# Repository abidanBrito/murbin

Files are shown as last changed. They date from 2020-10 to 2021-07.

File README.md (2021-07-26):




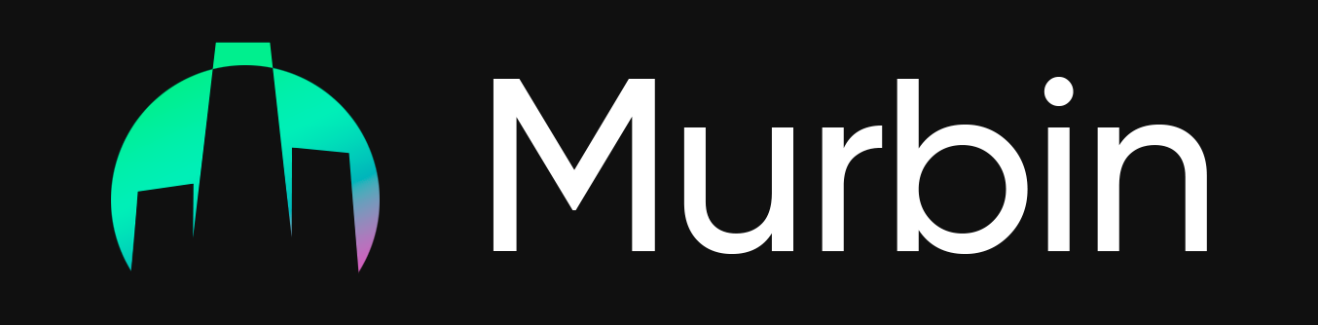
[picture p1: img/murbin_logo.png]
Project_Logo


## TABLE OF CONTENTS
1.  [Motivation](#motivation)
2.  [Technologies and Frameworks](#technologies-and-frameworks)
3.  [System Architecture](#system-architecture-outdated-diagram)
4.  [Functionalities and Features](#functionalities-and-features)
5.  [Documentation](#documentation)
6.  [Acknowledgements](#acknowledgements)

## MOTIVATION
This project is a team effort for our third semester class **Internet of Things** (IoT). It aims to implement **smart streetlighting** in a way that is **not only efficient**, but also provides some **added functionalities** and interaction with the user via an **Android App**.

## TECHNOLOGIES AND FRAMEWORKS
### Electronic Devices and Components
*   **Raspberry Pi 3 B**.
*   **ESP32 Devkit v1 WiFi + Bluetooth**.
*   **M5Stack** Modular Rapid Prototyping.
*   MQ-135 **Gas Sensor** Module.
*   DHT11 **Temperature and Humidity Sensor** Module.
*   KY-038 **Microphone Sound Sensor** Module.
*   HC-SR501 **PIR Sensor** Module. 
*   **Sonoff Touch** with Tasmota Firmware.
*   Operational Amplifiers.
*   Yxo Yuxinou **LED COB Chip** (220-265V/AC, 20W, 3500k/450nm/380-780nm).
*   NeoPixel Ring - **24 x 5050 RGB LED** with Integrated Drivers
*   Photodiode.
*   Resistors.
*   Relay.

### Mobile / Cloud Platforms & Protocols
*   **Android Things** embedded Operating System.
*   **Firebase**. 
*   **MQTT**.
*   **UDP**.

### Software Development 
*   Arduino IDE. 
*   Android Studio.
*   FreeRTOS.   

## SYSTEM ARCHITECTURE (OUTDATED DIAGRAM)
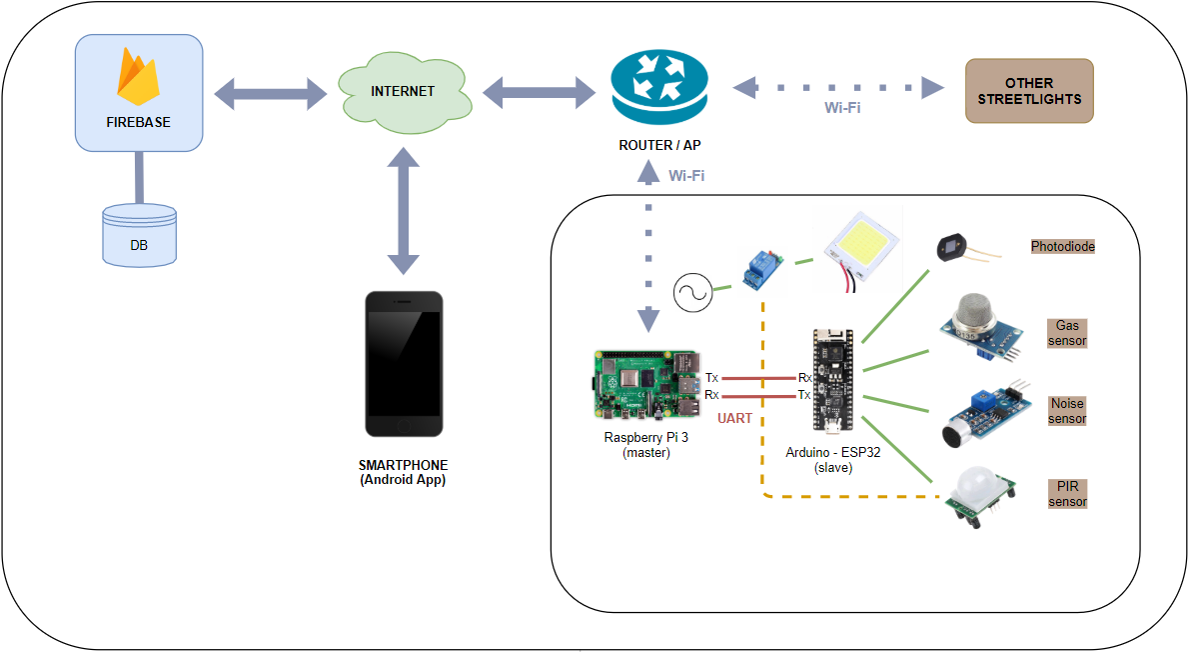
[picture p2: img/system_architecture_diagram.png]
System Architecture Diagram

Refer to the [documentation](docs/Documento_Técnico_Diseño_v3.pdf) (spanish) for further details and schematics.

## FUNCTIONALITIES AND FEATURES 
*   \[x] High **CO2 and Pollution** Detection.
*   \[x] **Temperature and Humidity** Sensor.
*   \[x] **Noise** Sensor.
*   \[x] **Motion Detection**.
*   \[x] **Luminosity** Sensor.
*   \[x] **Flashing LED** alarms.
*   \[x] Interactive **Mobile App** (ON/OFF switch, sensor readings, geolocation, map subzones and different user roles).
*   \[x] **Light Sleep** Mode.
*   \[x] **PCB** design.
*   \[ ] Dimming LED.

## DOCUMENTATION
It can be found in the form of a PDF file for each and every Sprint, accordingly. Those of previous Sprints may contain errors (schematics, pins, etc.). Please, refer to the lastest version: [technical documentation](docs/Documento_Técnico_Diseño_v3.pdf) (spanish). 

## ACKNOWLEDGEMENTS
We would like to express our sincere gratitude to our **professors** for their invaluable support, feedback and encouragement throughout the development of this project, and to **Universitat Politècnica de València** for providing us with both the knowledge and the tools needed to complete it.

## LICENSE
This repository is released under the MIT license. See [LICENSE.md](LICENSE.md) for more information.

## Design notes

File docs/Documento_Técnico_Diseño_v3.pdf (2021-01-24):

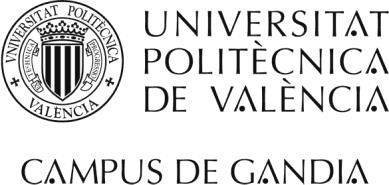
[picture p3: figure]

## Proyecto GTI_2A (GTI_2A_20_TEAM_12)

## Murbin - Farolas inteligentes

## Documento Técnico de Diseño

### Volumen 2

Documento Técnico de Diseño | Pag.ii
GTI_2A_20_TEAM_12
Vol. 1

### ÍNDICE

1.3 EQUIPO DE DESARROLLO E INTERESADOS EN EL PROYECTO ........4

Documento Técnico de Diseño | Pag.1

### 1 INTRODUCCIÓN

Murbin (Mobiliario urbano inteligente) plantea un prototipo de alumbrado público inteligente. Más concretamente, en nuestro caso, ser un sistema inteligente implica varias cosas: la conexión a Internet, la capacidad de realizar lecturas de diversas magnitudes físicas, así como la transmisión de éstas a posteriori y la activación automática de comportamientos preestablecidos (actuadores) en función del valor de medidas nominales. Por tanto, se trata de un proyecto que recae sobre el marco del Internet de las cosas (IoT) y requiere de numerosas tecnologías y disciplinas de la ingeniería.

Se recopila información sensible de campo, a fin de monitorizar y optimizar la actividad ambiental (intensidad de la luz, contaminación, nivel de ruido, presencia humana, geolocalización del dispositivo, etc.). Se propone implementar también un mecanismo de autoabastecimiento (célula fotovoltaica, batería y convertidor buck-boost). Para minimizar el consumo energético, se prevee la realización de las mediciones cada cierto tiempo. Ésto es configurable. Inmediatamente entraría en modo de hibernación o stand-by, hasta la siguiente captura de datos o el acaecimiento de una interrupción producida por alguna subrutina.

Para implementar las susodichas funcionalidades, se ha optado por utilizar el microcontrolador ESP32 (como esclavo), y el micro-ordenador Raspberry Pi 3 (como maestro). También son necesarios múltiples dispositivos y componentes electrónicos (resistencias, amplificadores operacionales, diodos, termistores, sensores específicos, …). El ESP32 puede ser programado utilizando la plataforma de desarrollo Arduino.

### 1.1 PROPÓSITO

En este documento se especifica el planteamiento inicial de las características técnicas del producto, así como su funcionamiento. Además, proporciona información sobre los dispositivos y tecnologías utilizados. Éste es un documento técnico dirigido a un público con conocimiento tecnológico mínimo, relativo al campo de la electrónica y la programación. Su redacción pretende exponer de manera rigurosa y objetiva las capacidades, propiedades y limitaciones del sistema. Con ello, se espera concretar las amplias posibilidades del producto.

### 1.2 ALCANCE

El término de alumbrado público inteligente hace referencia a alumbrado capaz de detectar diferentes niveles de magnitud y adaptar la intensidad de la luz de manera proporcional. Es decir, para diferentes condiciones la actuación de la farola será diferente. La intensidad baja cuando no se detecta movimiento y, por el contrario, sube cuando se detecta. Esto supone un cambio drástico de paradigma; contrasta con el tradicional alumbrado estático de intensidad variable por tiempos fijos (programado con reloj). Las posibilidades se extienden más allá de la luminosidad, permitiéndonos interactuar con los usuarios del medio público de manera acorde a la situación. Otro ejemplo sería el de cambiar la temperatura de los haces de luz en función del nivel de ruido del entorno. Así pues, es un sistema directamente ligado al desarrollo y la evolución de las Smart Cities [1] [2] [3].

Aclarado esto, los objetivos del producto son la optimización y reducción del consumo energético, el control de la contaminación en sus múltiples expresiones (sonora, lumínica y CO2), mejorar la experiencia de usuario del viandante y la creación de una interfaz homogénea y céntrica (aplicación Android) para consultas varias: búsqueda de parking, trazado de caminos, alertas personalizadas en función del nivel de ruido u otras magnitudes de interés, mapas de calor y un largo etcétera.

También estará equipado con un sistema de posicionamiento global, bien sea un recibidor GPS físico (hardware) o un par de coordenadas geográficas fijadas durante la instalación (software). Además el dispositivo ha de ser hermético; se puede estropear si alguno de sus componentes internos entra en contacto con el agua, provocando un cortocircuito.

Cabe recalcar que solo se han mencionado algunas de las funcionalidades pensadas desde un punto de vista empático con el perfil de usuario del viandante. No obstante, se han definido otros perfiles como el del técnico, el administrador y (opcionalmente) el investigador o científico. Las funcionalidades a implementar deberán ser específicas (por lo general) al tipo de usuario en cuestión. Véanse debajo los perfiles de usuario estudiados y los porcentajes aproximados que se sopesan.

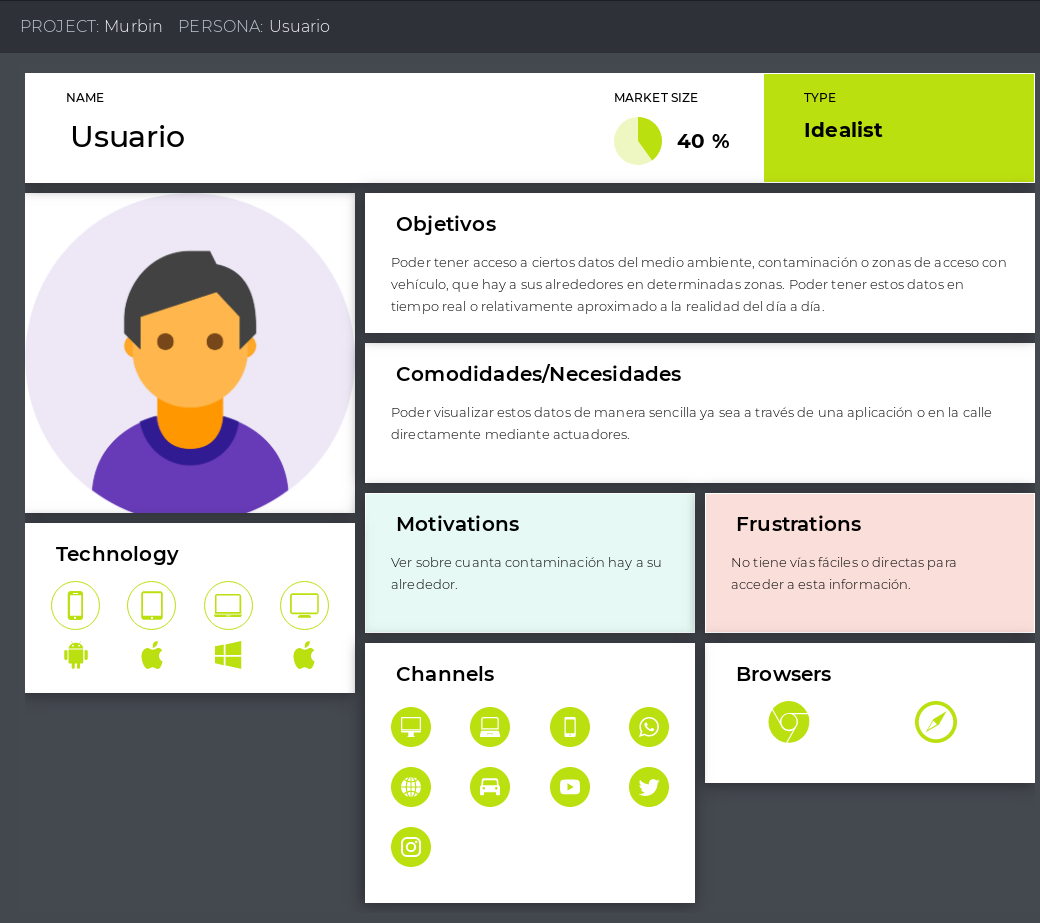
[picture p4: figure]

Ilustración 1. Perfil de usuario (usuario).

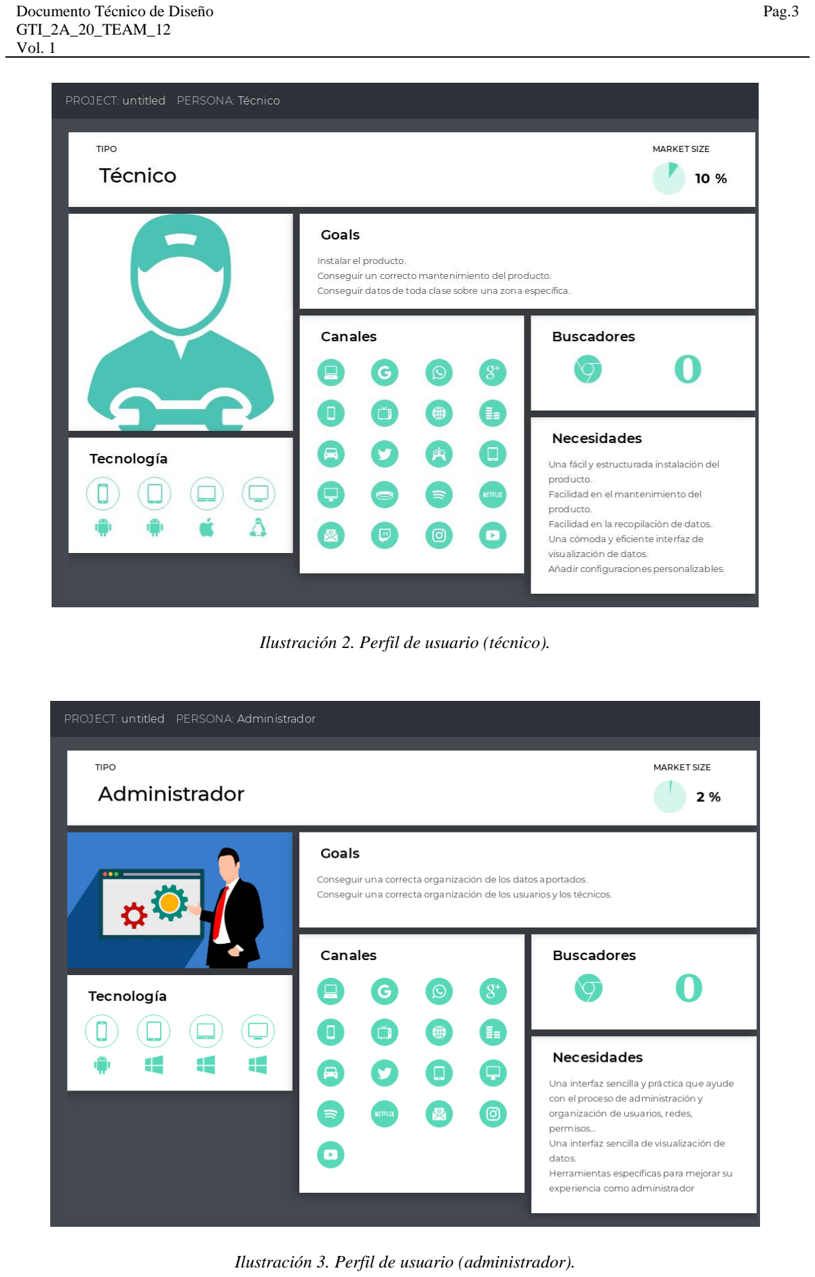
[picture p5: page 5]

Ilustración 2. Perfil de usuario (técnico).

Ilustración 3. Perfil de usuario (administrador).

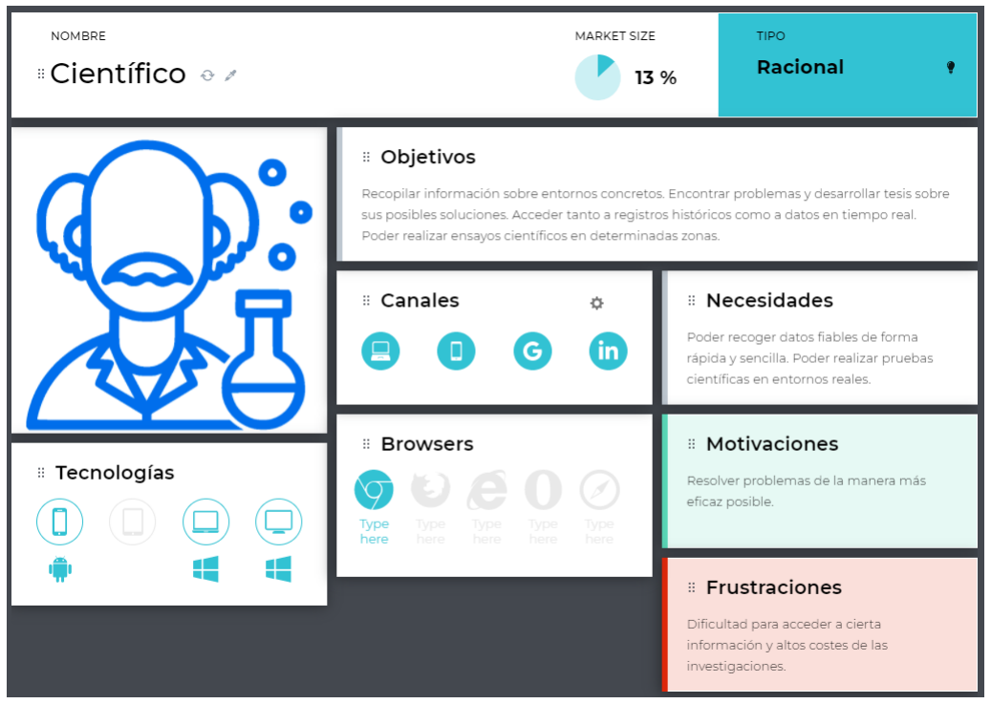
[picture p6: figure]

Ilustración 4. Perfil de usuario (científico).

### 1.3 EQUIPO DE DESARROLLO E INTERESADOS EN EL PROYECTO

A continuación se listan todos los integrantes del equipo de desarrollo del proyecto, así como algunas personalidades de interés por su carácter asesorativo y/o de formación.

Miembros del equipo

Abidán Brito Clavijo

- Estudiante de 2º del grado en Tecnologías Interactivas.
- Manager del equipo.
- Desarrollo electrónico.
- Desarrollo software embebido.

Alejandro Losa García

- Estudiante de 2º del grado en Tecnologías Interactivas.
- Diseño visual y de interacción.
- Maquetación interfaz gráfica.

Francisco Javier Paños Madrona

- Estudiante de 2º del grado en Tecnologías Interactivas.
- Desarrollo de aplicación Android.

Yeray Candel Sampedro

- Estudiante de 2º del grado en Tecnologías Interactivas.
- Desarrollo electrónico.
- Desarrollo software embebido.

Raúl De La Fe Robles

- Estudiante de 2º del grado en Tecnologías Interactivas.
- Generalista.

Otros interesados en el proyecto

José Marín-Roig Ramón

- Profesor Titular en Universitat Politècnica de València.
- Product Owner.
- Asesor.

Jesús Tomás Gironés

- Profesor Titular en Universitat Politècnica de València.
- Formación teórica Android.
- Asesor.

Stella María Heras Barberá

- Profesora Asociada en Universitat Politècnica de València.
- Formación práctica Android.
- Asesora.

Enrique Colomar Pous

- Profesor Titular en Universitat Politècnica de València.
- Formación práctica de laboratorio (desarrollo electrónico).

Tomás Carlos Sogorb Devesa

- Profesor Titular en Universitat Politècnica de València.
- Formación teórica microprocesadores y acondicionadores de señal.

### 1.4 DEFINICIONES, ACRÓNIMOS Y ABREVIATURAS

- IDE: entorno de desarrollo integrado (Integrated Development Environment).
- TCP: Transmission Control Protocol.
- IP: Internet Protocol address.
- UDP: User Datagram Protocol.
- HTTP: Hypertext Transfer Protocol.
- MQTT: Message Queuing Telemetry Transport.
- UART: Universal Asynchronous Receiver-Transmitter.
- GPS: Global Positioning System.

### 1.5 ESTRUCTURA DEL DOCUMENTO

El documento se estructura de la siguiente manera:

/1 | La Sección 1 es la introducción e incluye una descripción detallada del proyecto y los documentos referenciados.
/2 | La Sección 2 proporciona una visión general del sistema.
/3 | La Sección 3 incluye el mapa de la red de nodos especificando las diferentes capas
/4 | La Sección 4 presenta las conclusiones del trabajo desarrollado y las posibles líneas de mejora.
/5 | Por último, se presentan las referencias del documento

### 1.6 REPOSITORIO GIT Y LISTADO DOCUMENTAL

Para la base de código y documentos pertinentes a este proyecto, se ha utilizado un repositorio Git como sistema de control de versiones, alojado en la plataforma GitHub. Para acceder al repositorio, haga click sobre el hipervínculo aquí expuesto:

https://github.com/abidanBrito/murbin

### 2 SISTEMA

### 2.1 CARACTERÍSTICAS DEL SISTEMA

El sistema aquí expuesto parte del microcontrolador ESP32 V1, o un M5Stack acoplado al micro-ordenador Raspberry Pi 3. De esta manera podemos tener una red de sensores centralizada. Además, no es necesario el uso de un convertidor Analógico-Digital externo.

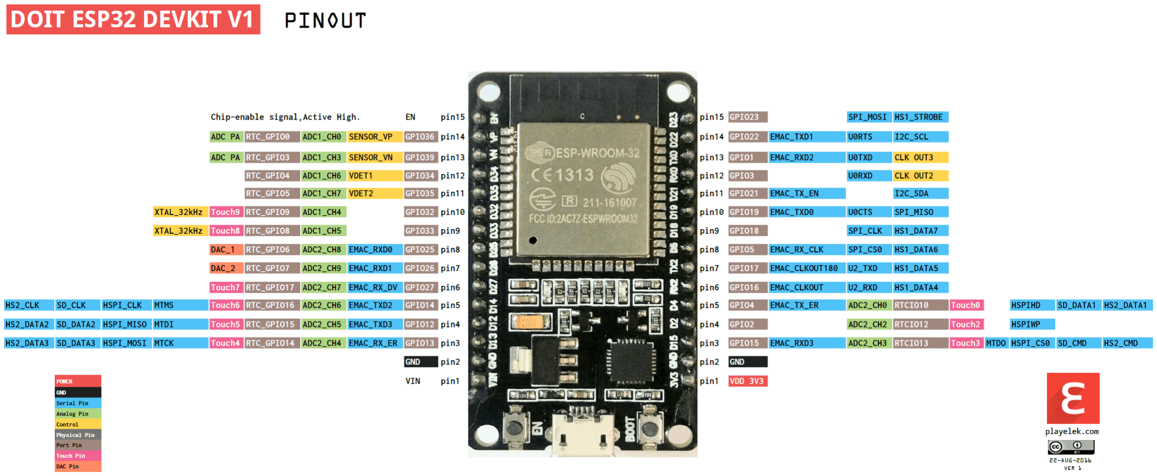
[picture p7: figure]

Ilustración 5. Esquema de pines del ESP32.

Lo primero que se debe hacer es establecer una línea de tierra. Los pines de GND han de coincidir, y se ha de tener especial precaución con el sentido en que se acoplan los pines. Si se hiciese en una orientación errónea, se podría cortocircuitar la placa.

El circuito del Transmisor-Receptor Asíncrono Universal (UART) controla los puertos y dispositivos serie. Se utilizará para interconectar el microprocesador y el microcontrolador, mediante un protocolo de comunicación en serie. De esta manera permitimos el análisis en tiempo real con el monitor en serie del Arduino IDE o el equivalente Logcat del Android Studio. La velocidad de transferencia ha de ser la misma para maestro y esclavo, para que la transmisión de datos coincida. Nótese que la placa ESP32 solo tiene un UART. Es decir, no pueden haber varios periféricos conectados al mismo tiempo por la misma UART. La transmisión/recepción de datos se lleva a cabo por los pines TXD y RXD. No obstante, al conectar la placa al PC por el puerto microUSB, se conecta directamente al UART.

Nuestro sistema realiza lecturas analógicas de los diversos sensores a través de los pines GPIO. La mayoría de estos pines se enc uentran conectados internamente a un ADC (convertidor analógico-digital).

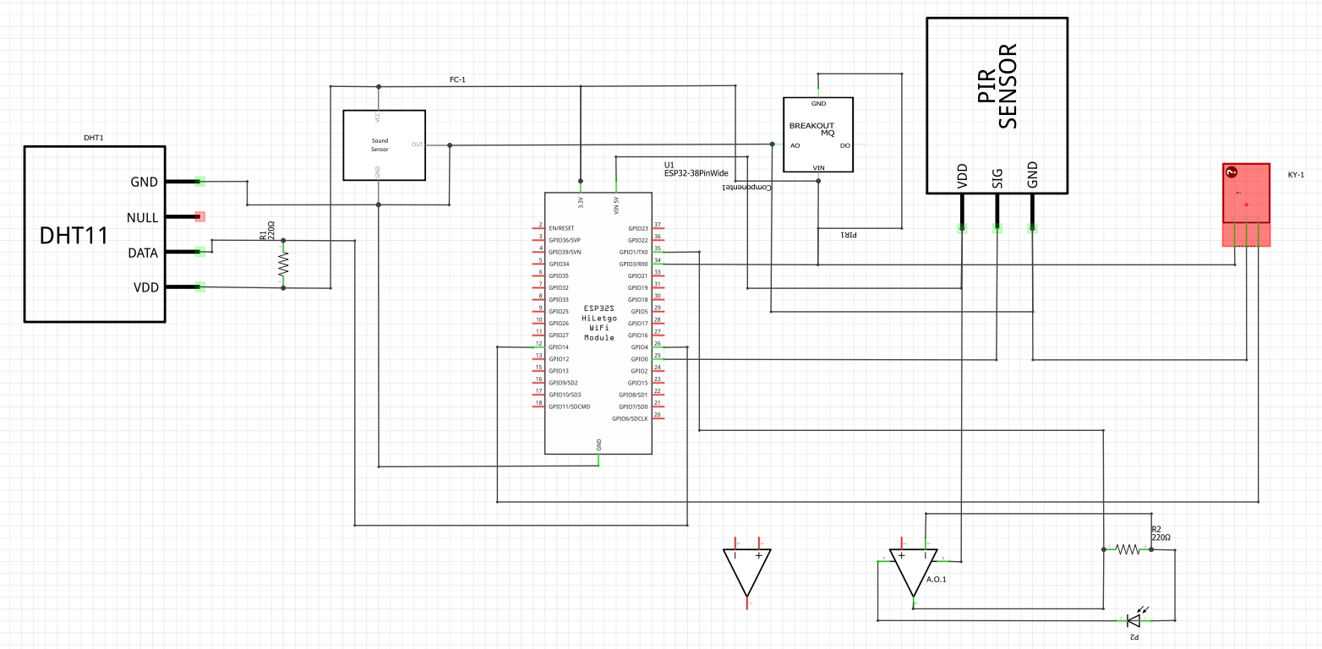
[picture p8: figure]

Ilustración 6. Esquemático de los sensores.

La directiva 2011/65/UE es aplicable. El producto también cumple la normativa europea de concentración máxima de sustancias peligrosas. El reciclaje de aparatos eléctricos y electrónicos es una cuestión sensible. Éstos están formados por diferentes materias peligrosas. La negligencia de su correcto tratamiento o reciclaje puede suponer contaminación ambiental. Siguiendo el Real Decreto 110/2015, se insta a extraer los componentes internos de la caja y llevarlos al punto limpio más cercano; depositando la caja y los residuos electrónicos por separado y en sus respectivas localizaciones. El reciclaje de los RAEE depende del papel activo de Documento Técnico de Diseño Pág.9 GTI 1A 19 TEAM 02 Vol. 1 cada uno de nosotros. Debemos concienciarnos y entender la responsabilidad y deuda ecológica que ello conlleva. Todos los sensores implementados cumplen la normativa RoHS: MPU-9250, BMP280, A2235-H.

### 2.2 ARQUITECTURA DEL SISTEMA

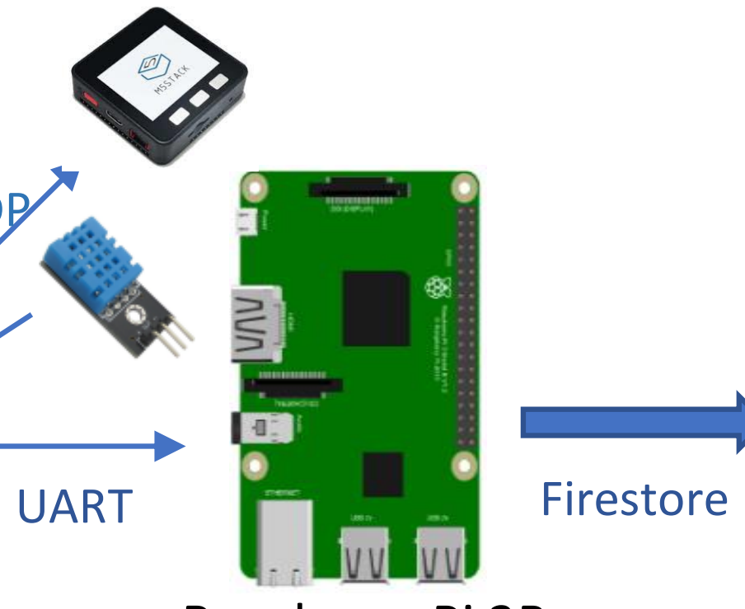
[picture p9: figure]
UART; Firestore
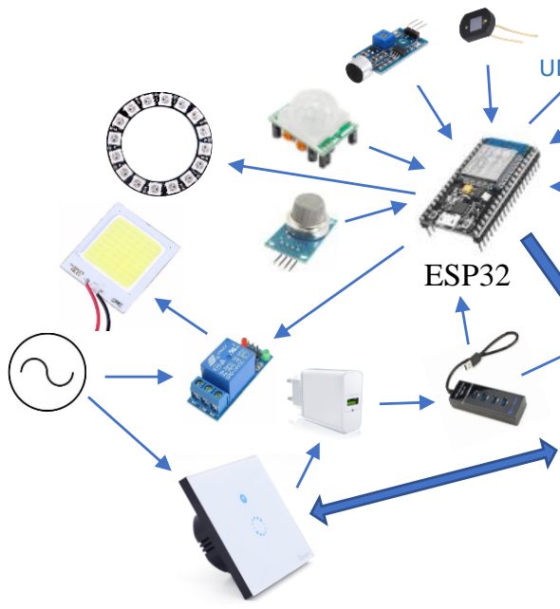
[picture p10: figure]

Ilustración 7. Diagrama de conexiones del sistema.

ESP32 | Raspberry Pi 3B

Smartphone

Broker
MQTT

Sonoff Touch
conexión inalámbrica
conexión por cable

UDP

Ilustración 8. Diagrama de Comunicaciones del sistema.

MQTT
murbin/
ON / OFF

murbin/
TOGGLE

MQTT

murbin/sensores/tipo_sensor MEDICION

Firestore

streetlight/sensors/tipo_sensor value=numero

MQTT

murbin/
ON / OFF

Firestore
streetlight/sensors/tipo_sensor value=numero

zones/subzones/streetlights
Firestore | name=string
users/
value=id

UART
(testeo)

UDP

### 3 RED DE NODOS

Se puede desglosar el camino de los datos de manera esquemática en los siguientes 5 niveles:
1. Comunicación hardware (nivel 0).
2. Acceso a la red (nivel 1).
3. Internet (nivel 2).
4. Transporte (nivel 3).
5. Aplicación (nivel 4).

En primer lugar nuestro microcontrolador realiza lecturas analógicas de los sensores a través de los pines GPIO, y con la Raspberry Pi mediante el protocolo UART (con la finalidad de enviar los datos capturados). Éstos, son enviados mediante conexión inalámbrica (Wi-Fi) a un servidor en la nube y almacenados en una base de datos NoSQL (Firebase), utilizando el protocolo IP. Ya que la conexión a Internet es la función que más consume, y no es necesario enviar datos en grandes cantidades, se podría utilizar el protocolo TCP o el UDP. Finalmente estos datos acaban en el servidor web mediante el protocolo HTTP. Nótese que, en la práctica no sería necesario tener el prototipo conectado a ningún otro dispositivo, pues es autosuficiente y los datos serían enviados directamente al servidor. A continuación, adjuntamos la siguiente ilustración a modo de ayuda visual. También se utiliza el protocolo MQTT como pasarela de comunicación entre los distintos dispositivos, para el envío y recepción de datos.

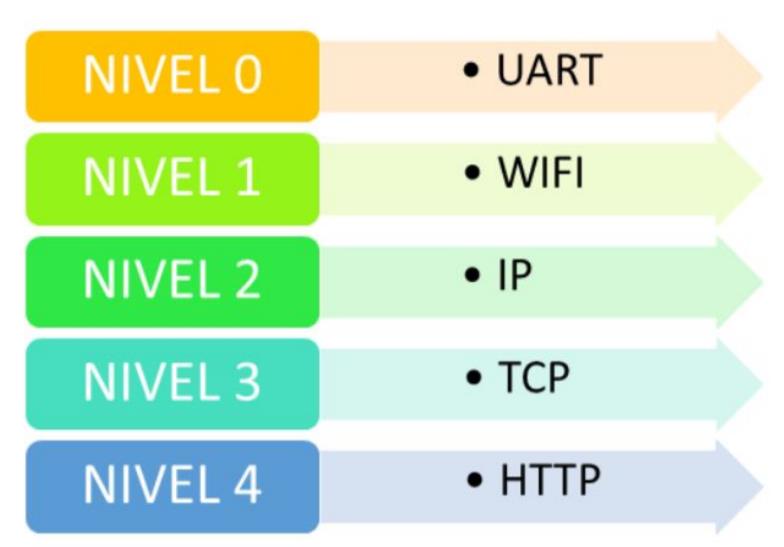
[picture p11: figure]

Ilustración 9. Red de nodos.

### 4 FUNCIONALIDADES SENSOR

### 4.1 SENSOR KY-038

El sensor de sonidoKY038 para Arduino está diseñado con un pequeño micrófono electrito que detecta las variaciones de ruido del ambiente.

Los micrófonos electret tienen una respuesta en frecuencia bastante buena (50 a 15.000 Hz) y una sensibilidad entre -50 dB y -70 dB, aunque lejana de la de los micrófonos de condensador, que son mucho más sensibles en la zona de los agudos). Además, es una respuesta poco plana.

Entre sus principales ventajas destaca su insensibilidad a la humedad y el calor (aunque la humedad y las partículas causen un cortocircuito en parte del diafragma, siempre se obtiene señal eléctrica a la salida).

El principal inconveniente que presentan los micrófonos electret es el polvo, que deteriora su rendimiento con el uso. Cuando un micrófono electret empieza a producir zumbidos (ruidos) inexplicables, es una indicación de que debe ser sustituido, ya que ha terminado su vida activa.

Puedes utilizar este sensor para tus proyectos que requieran la detección de ruido, como ser alarmas o interruptores con detección de voz o sonido (un aplauso, por ejemplo).

De manera general, estos son algunos rangos de operación típicos que son útiles de tenerlos en cuenta a la hora de implementar un circuito con este sensor.

- Voltaje de trabajo: 5.0V
- Muy bajo consumo de corriente
- Temperatura de trabajo: -40 < T < +85 ºC

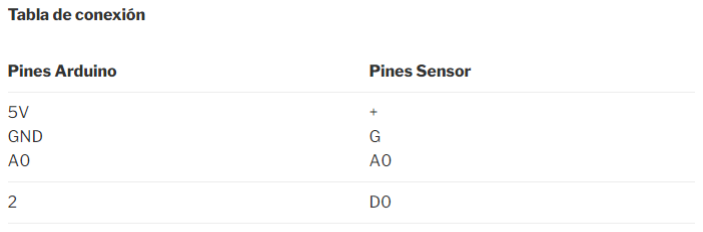
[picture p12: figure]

### 4.1.1.1 Circuito del sensor de sonido KY038

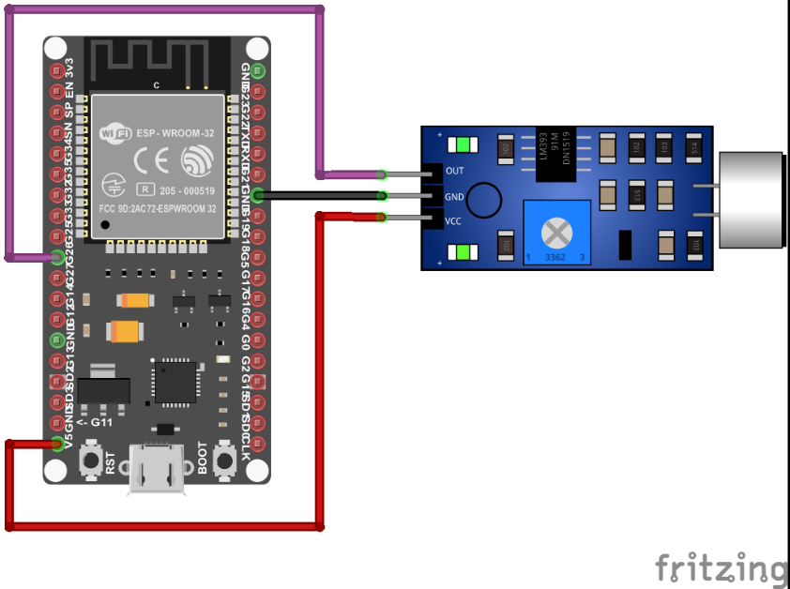
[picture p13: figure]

### 4.2 SENSOR PIR

Los detectores PIR (Passive Infrared) o Pasivo Infrarrojo, reaccionan sólo ante determinadas fuentes de energía tales como el calor del cuerpo humano o animales. Básicamente reciben la variación de las radiaciones infrarrojas del medio ambiente que cubre. Es llamado pasivo debido a que no emite radiaciones, sino que las recibe. Estos captan la presencia detectando la diferencia entre el calor emitido por el cuerpo humano y el espacio alrededor.

Su componente principal son los sensores piroeléctricos. Se trata de un componente electrónico diseñado para detectar cambios en la radiación infrarroja recibida. Generalmente dentro de su encapsulado incorporan un transistor de efecto de campo que amplifica la señal eléctrica que genera cuando se produce dicha variación de radiación recibida.

La información infrarroja llega al sensor piroeléctrico a través de una lente de fressnell que divide el área protegida en sectores. Se distribuyen lentes con diferentes características: gran angular, cortina, corredor, anti mascotas, etc.

Los sensores PIR son ampliamente usados en sistemas de seguridad y en detección de intrusos en entornos domésticos y comerciales, ya que se pueden instalar en cualquier punto de entrada potencial (puertas y ventanas) y avisar de la presencia de los intrusos antes de que lleguen al sensor y lo puedan sabotear.

### 4.2.1.1 Circuito del sensor PIR

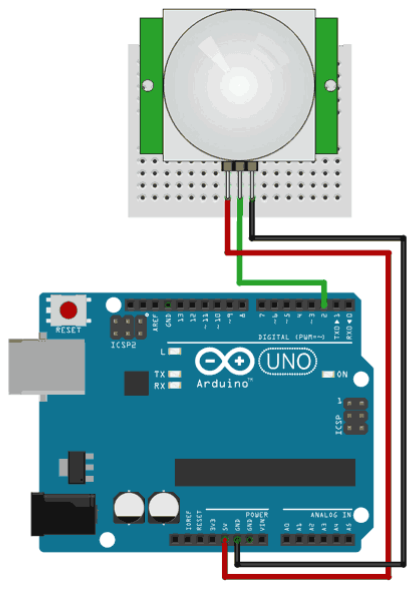
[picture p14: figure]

### 4.3 SENSOR MQ4

Los sensores de gases MQ son una familia de dispositivos diseñados para detectar la presencia de distintos componentes químicos en el aire. Podemos conectar estos dispositivos a un autómata o procesador como Arduino.

Existe una gran variedad de sensores MQ. Cada modelo está diseñado para detectar una o más sustancias, pensadas para un uso específico, como por ejemplo detección gases inflamables, calidad del aire o detección de alcohol en aire respirado.

Los sensores de gases deben ser calibrados antes de obtener una medida precisa. Aun calibrados estos sensores no disponen de la garantía necesaria para formar parte de un sistema de seguridad.

Los sensores MQ están compuestos por un sensor electroquímico que varía su resistencia al estar en contacto con las sustancias.

Los sensores de gases son dispositivos con alta inercia, es decir, la respuesta necesita tiempos largos para estabilizarse tras un cambio de concentración de los gases medidos. Ello es debido a la necesidad física de que el gas abandone el material sensible, lo cual es un proceso lento.

Todos los modelos MQ disponen de un calentador necesario para elevar la temperatura del sensor, y que sus materiales adquieran la sensibilidad. Mientras el calentador no alcance la temperatura de funcionamiento, la lectura del sensor no será fiable.

El tiempo de calentamiento depende de cada modelo de sensor. En la mayoría de las modelos es suficiente para con unos pocos minutos, pero algunos modelos requieren hasta 12 y 48 horas hasta obtener mediciones estables.

Por otro lado, cada modelo necesita su propia tensión para alimentar el calentador. En muchos modelos esta tensión es de 5V, pero algunos modelos tienen condicionantes especiales para la alimentación.

El consumo de los sensores MQ puede ser elevado debido al calor necesario para funcionar el calentador, que puede llegar hasta 800 mW en algunos modelos. Esto es superior a la potencia que puede suministrar el regulador de Arduino, por lo que será necesario proporcionar una fuente de alimentación externa.

A continuación, una tabla de resumen con los distintos modelos de sensores disponibles, los gases a los que son sensibles, y algunos datos sobre el calentador. Nosotros utilizaremos el MQ-135.

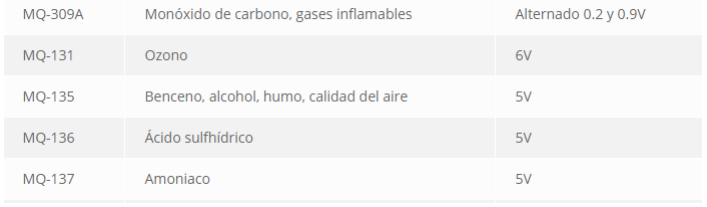
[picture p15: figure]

### 4.3.1.1 Circuito del sensor de gas MQ-4

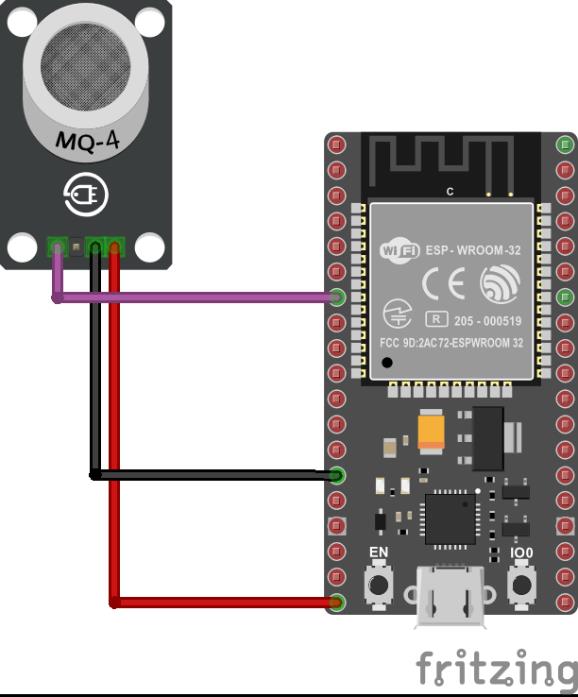
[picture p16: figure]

### 4.4 SENSOR LUMINOSIDAD

Un fotorresistor, o LDR (light-dependent resistor) es un dispositivo cuya resistencia varía en función de la luz recibida. Podemos usar esta variación para medir, a través de las entradas analógicas, una estimación del nivel de la luz.

Un fotorresistor está formado por un semiconductor, típicamente sulfuro de cadmio CdS. Al incidir la luz sobre él algunos de los fotones son absorbidos, provocando que electrones pasen a la banda de conducción y, por tanto, disminuyendo la resistencia del componente.

Por tanto, un fotorresistor disminuye su resistencia a medida que aumenta la luz sobre él. Los valores típicos son de 1 Mohm en total oscuridad, a 50-100 Ohm bajo luz brillante.

Por otro lado, la variación de la resistencia es relativamente lenta, de 20 a 100 ms en función del modelo. Esta lentitud hace que no sea posible registrar variaciones rápidas, como las producidas en fuentes de luz artificiales alimentadas por corriente alterna. Este comportamiento puede ser beneficioso, ya que dota al sensor de una gran estabilidad.

Finalmente, los fotorresistores no resultan adecuados para proporcionar una medición de la iluminancia, es decir, para servir como luxómetro. Esto es debido a su baja precisión, su fuerte dependencia con la temperatura y, especialmente, a que su distribución espectral no resulta adecuada para la medición de iluminancia.

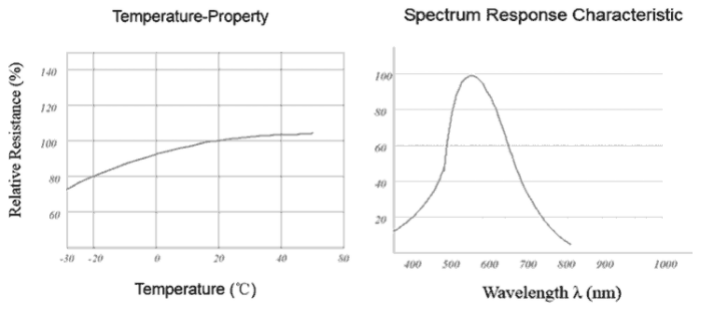
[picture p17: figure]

Matemáticamente, la relación entre la iluminancia y la resistencia de una LDR sigue una función potencial.

Siendo R0 la resistencia a una intensidad I0, ambas conocidas.

La constante gamma es la pendiente de la gráfica logarítmica, o la pérdida de resistencia por década. Su valor típicamente 0.5 a 0.8.

Por este motivo, frecuentemente las gráficas que relacionan ambos valores se representan en escalas logarítmicas para ambos ejes. Bajo esta representación, la relación se muestra como una gráfica lineal.

### 4.4.1.1 Circuito del sensor PIR

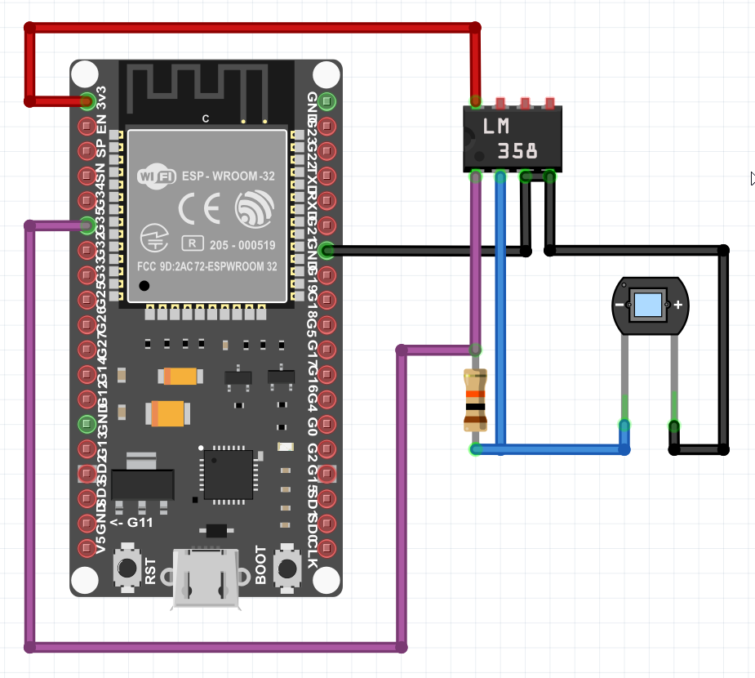
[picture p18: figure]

### 4.5 SENSOR DHC11

El DHT11 y el DHT22 (o AM2302) son dos modelos de una misma familia de sensores, que permiten realizar la medición simultánea de temperatura y humedad.

Estos sensores disponen de un procesador interno que realiza el proceso de medición, proporcionando la medición mediante una señal digital, por lo que resulta muy sencillo obtener la medición desde un microprocesador como Arduino.

Ambos sensores presentan un encapsulado de plástico similar. Podemos distinguir ambos modelos por el color de este. El DHT11 presenta una carcasa azul, mientras que en el caso del sensor DHT22 el exterior es blanco.

De ambos modelos, el DHT11 es el hermano pequeño de la familia, y cuenta peores características técnicas. El DHT22 es el modelo superior, pero, por contra, tiene un precio superior.

Las características del DHT11 son en realidad escasas, especialmente en rango de medición y precisión.

- Medición de temperatura entre 0 a 50, con una precisión de 2ºC
- Medición de humedad entre 20 a 80%, con precisión del 5%.
- Frecuencia de muestreo de 1 muestras por segundo (1 Hz)

El DHT11 es un sensor muy limitado que podemos usar con fines de formación, pruebas, o en proyectos que realmente no requieran una medición precisa.

### 4.5.1.1 Circuito del sensor PIR

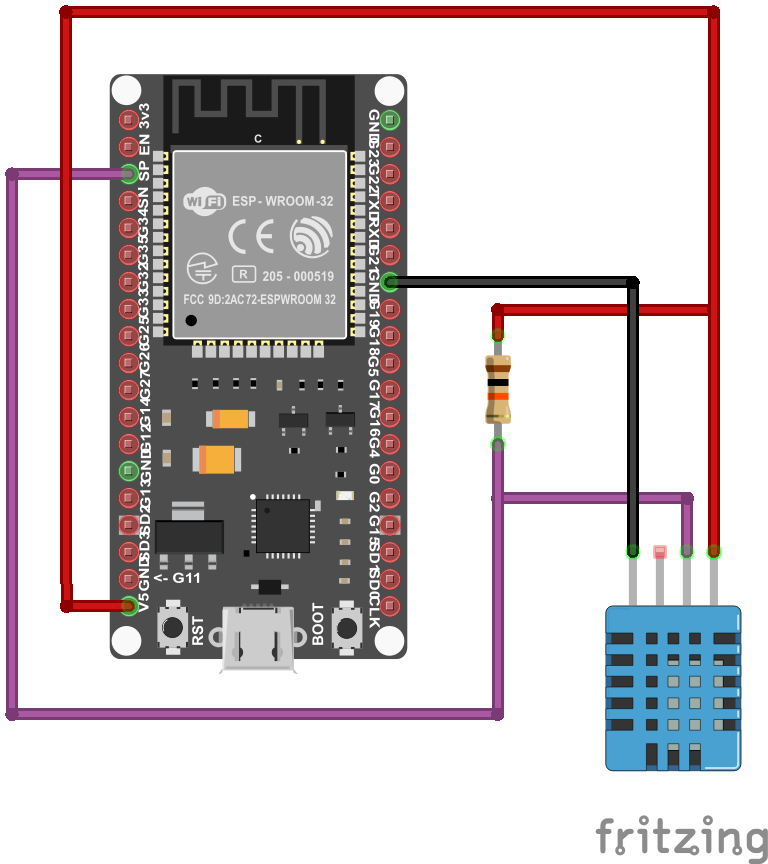
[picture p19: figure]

### 5 ESTUDIO DE ENERGIA Y CONSUMO

También se han optimizado el consumo energético al máximo, optando por soluciones renovables, limpias y efectivas, así como usando la hibernación del microcontrolador y diseñando una PCB específica para esta primera versión del prototipo, también emos optado por la programación con tareas para reducir el uso innecesario. Todo ello de acuerdo con la normativa medioambiental vigente.

GTI_

2A_20_TEAM_12
Vol.

1

### 6 CONCLUSIONES Y LÍNEAS DE MEJORA

Tras la implementación de la segunda versión del producto (prototipo del Sprint 3) se extraen las siguientes conclusiones:
- Se ha ampliado la red de sensores interconectada de manera inalámbrica a Internet (tecnología Wi-Fi). A medida que avance el desarrollo la red de sensores seguirá creciendo en magnitud.
- Se ha terminado el wireframe (layouts) de la aplicación, teniendo en cuenta el diseño visual, el diseño de interacción y la experiencia de usuario de la aplicación móvil.
- Se ha creado terminado la base de datos NoSQL en tiempo real.
- Se ha maquetado y configurado una primera versión de la aplicación móvil (Android) con varios roles de usuario autentificados, así como el tipo de usuario invitado.
- Se han implementado nuevos actuadores y se hace uso de relés.
- Se han reemplazados los LEDs individuales por actuadores propios (anillo de LEDs y foco LED). Èsto implica concebir las funcionalidades de los distintos perfiles de usuario ya definidos.
- Se han de realizar el calibrado de los sensores para el siguiente Sprint.

### REFERENCIAS

[1] Zak Derler (2020). Smart street lighting will help future-proof our cities. (https://www.climatechangenews.com/2020/06/12/smart-street-lighting-will-help-future-proof-cities/)
[2] Esther Fuldauer (2019). Lighting the road to smart cities and sustainability. (https://www.smartcitylab.com/blog/urban-environment/lighting-the-road-to-smart-cities-and-sustainability/)
[3] Chris Teale (2020). Cities ‘finally waking up’ to the benefits of smart streetlights: survey. (https://www.smartcitiesdive.com/news/survey-smart-streetlights-LED-northeast-group/577227/) Wikipedia (2014). Intelligent street lighting. (https://en.wikipedia.org/wiki/Intelligent_street_lighting)
Wikipedia (2020). Universal asynchronous receiver-transmitter. (https://en.wikipedia.org/wiki/Universal_asynchronous_receiver-transmitter)
Campbell, Scott (2016). Basics of UART Communication. (https://www.shorturl.at/btwBS)
Loflin, Lewis (2018). Photodiode Circuit Operation and Uses. (http://www.bristolwatch.com/ele2/pdiodeTran.htm)
Universitat Politècnica de València (2017). Master en Desarrollo de Aplicaciones Android. (http://www.androidcurso.com/) Gironés, T. (2013). El gran libro de Android. Barcelona: Marcombo.

### CONTROL DEL DOCUMENTO

Título: | Documento Técnico de Diseño
Volumen: | Vol. 2
Fecha: | 21 Enero 2021
Autor: | Raúl de la Fe Robles
Referencia: | GTI_20_2A_TEAM_12
Nombre de fichero: | GTI_20_2A_TEAM_12-01

### FIRMAS DEL DOCUMENTO

Naturaleza del firmante | Nombre | Firma | Fecha | Rol
Autor | Abidán Brito Clavijo Raúl de la Fe Robles Javier Paños Madrona Alejandro Losa García Yeray Candel Sampedro | | 21/1/2021 | Miembros del equipo.

Revisor

### REGISTRO DE CAMBIOS DEL DOCUMENTO

Fecha | Versión | Autor | Detalles de los cambios
20 Ocubre 2020 | Vol 1. Borrador 1 | Abidán Brito Clavijo. | Primer borrador del sistema (Sprint 1).
19 Noviembre 2020 | Vol 2. Borrador 1. | Abidán Brito Clavijo | Segundo borrador del sistema (Sprint 2).
10 Diciembre 2020 | Vol 2. Borrador 2. | Abidán Brito Clavijo | Diagrama de conexiones, comunicaciones, corrección de los protocolos.
21 Enero 2021 | Vol 2. Borrador 3. | Raúl de la Fe Robles | Actualizar los elementos del documento.

Aportar información sobre: uso energético y
medioambiente.

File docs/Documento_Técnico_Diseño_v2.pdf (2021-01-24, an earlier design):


## Proyecto GTI_2A (GTI_2A_20_TEAM_12)

## Murbin - Farolas inteligentes

## Documento Técnico de Diseño

### Volumen 2

Documento Técnico de Diseño | Pag.ii
GTI_2A_20_TEAM_12
Vol. 1

### ÍNDICE

1.3 EQUIPO DE DESARROLLO E INTERESADOS EN EL PROYECTO ........4

Documento Técnico de Diseño | Pag.1

### 1 INTRODUCCIÓN

Murbin (Mobiliario urbano inteligente) plantea un prototipo de alumbrado público inteligente. Más concretamente, en nuestro caso, ser un sistema inteligente implica varias cosas: la conexión a Internet, la capacidad de realizar lecturas de diversas magnitudes físicas, así como la transmisión de éstas a posteriori y la activación automática de comportamientos preestablecidos (actuadores) en función del valor de medidas nominales. Por tanto, se trata de un proyecto que recae sobre el marco del Internet de las cosas (IoT) y requiere de numerosas tecnologías y disciplinas de la ingeniería.

Se recopila información sensible de campo, a fin de monitorizar y optimizar la actividad ambiental (intensidad de la luz, contaminación, nivel de ruido, presencia humana, geolocalización del dispositivo, etc.). Se propone implementar también un mecanismo de autoabastecimiento (célula fotovoltaica, batería y convertidor buck-boost). Para minimizar el consumo energético, se prevee la realización de las mediciones cada cierto tiempo. Ésto es configurable. Inmediatamente entraría en modo de hibernación o stand-by, hasta la siguiente captura de datos o el acaecimiento de una interrupción producida por alguna subrutina.

Para implementar las susodichas funcionalidades, se ha optado por utilizar el microcontrolador ESP32 (como esclavo), y el micro-ordenador Raspberry Pi 3 (como maestro). También son necesarios múltiples dispositivos y componentes electrónicos (resistencias, amplificadores operacionales, diodos, termistores, sensores específicos, …). El ESP32 puede ser programado utilizando la plataforma de desarrollo Arduino.

### 1.1 PROPÓSITO

En este documento se especifica el planteamiento inicial de las características técnicas del producto, así como su funcionamiento. Además, proporciona información sobre los dispositivos y tecnologías utilizados. Éste es un documento técnico dirigido a un público con conocimiento tecnológico mínimo, relativo al campo de la electrónica y la programación. Su redacción pretende exponer de manera rigurosa y objetiva las capacidades, propiedades y limitaciones del sistema. Con ello, se espera concretar las amplias posibilidades del producto.

### 1.2 ALCANCE

El término de alumbrado público inteligente hace referencia a alumbrado capaz de detectar diferentes niveles de magnitud y adaptar la intensidad de la luz de manera proporcional. Es decir, para diferentes condiciones la actuación de la farola será diferente. La intensidad baja cuando no se detecta movimiento y, por el contrario, sube cuando se detecta. Esto supone un cambio drástico de paradigma; contrasta con el tradicional alumbrado estático de intensidad variable por tiempos fijos (programado con reloj). Las posibilidades se extienden más allá de la luminosidad, permitiéndonos interactuar con los usuarios del medio público de manera acorde a la situación. Otro ejemplo sería el de cambiar la temperatura de los haces de luz en función del nivel de ruido del entorno. Así pues, es un sistema directamente ligado al desarrollo y la evolución de las Smart Cities [1] [2] [3].

Aclarado esto, los objetivos del producto son la optimización y reducción del consumo energético, el control de la contaminación en sus múltiples expresiones (sonora, lumínica y CO2), mejorar la experiencia de usuario del viandante y la creación de una interfaz homogénea y céntrica (aplicación Android) para consultas varias: búsqueda de parking, trazado de caminos, alertas personalizadas en función del nivel de ruido u otras magnitudes de interés, mapas de calor y un largo etcétera.

También estará equipado con un sistema de posicionamiento global, bien sea un recibidor GPS físico (hardware) o un par de coordenadas geográficas fijadas durante la instalación (software). Además el dispositivo ha de ser hermético; se puede estropear si alguno de sus componentes internos entra en contacto con el agua, provocando un cortocircuito.

Cabe recalcar que solo se han mencionado algunas de las funcionalidades pensadas desde un punto de vista empático con el perfil de usuario del viandante. No obstante, se han definido otros perfiles como el del técnico, el administrador y (opcionalmente) el investigador o científico. Las funcionalidades a implementar deberán ser específicas (por lo general) al tipo de usuario en cuestión. Véanse debajo los perfiles de usuario estudiados y los porcentajes aproximados que se sopesan.


Ilustración 1. Perfil de usuario (usuario).


Ilustración 2. Perfil de usuario (técnico).

Ilustración 3. Perfil de usuario (administrador).


Ilustración 4. Perfil de usuario (científico).

### 1.3 EQUIPO DE DESARROLLO E INTERESADOS EN EL PROYECTO

A continuación se listan todos los integrantes del equipo de desarrollo del proyecto, así como algunas personalidades de interés por su carácter asesorativo y/o de formación.

Miembros del equipo

Abidán Brito Clavijo

- Estudiante de 2º del grado en Tecnologías Interactivas.
- Manager del equipo.
- Desarrollo electrónico.
- Desarrollo software embebido.

Alejandro Losa García

- Estudiante de 2º del grado en Tecnologías Interactivas.
- Diseño visual y de interacción.
- Maquetación interfaz gráfica.

Francisco Javier Paños Madrona

- Estudiante de 2º del grado en Tecnologías Interactivas.
- Desarrollo de aplicación Android.

Yeray Candel Sampedro

- Estudiante de 2º del grado en Tecnologías Interactivas.
- Desarrollo electrónico.
- Desarrollo software embebido.

Raúl De La Fe Robles

- Estudiante de 2º del grado en Tecnologías Interactivas.
- Generalista.

Otros interesados en el proyecto

José Marín-Roig Ramón

- Profesor Titular en Universitat Politècnica de València.
- Product Owner.
- Asesor.

Jesús Tomás Gironés

- Profesor Titular en Universitat Politècnica de València.
- Formación teórica Android.
- Asesor.

Stella María Heras Barberá

- Profesora Asociada en Universitat Politècnica de València.
- Formación práctica Android.
- Asesora.

Enrique Colomar Pous

- Profesor Titular en Universitat Politècnica de València.
- Formación práctica de laboratorio (desarrollo electrónico).

Tomás Carlos Sogorb Devesa

- Profesor Titular en Universitat Politècnica de València.
- Formación teórica microprocesadores y acondicionadores de señal.

### 1.4 DEFINICIONES, ACRÓNIMOS Y ABREVIATURAS

- IDE: entorno de desarrollo integrado (Integrated Development Environment).
- TCP: Transmission Control Protocol.
- IP: Internet Protocol address.
- UDP: User Datagram Protocol.
- HTTP: Hypertext Transfer Protocol.
- MQTT: Message Queuing Telemetry Transport.
- UART: Universal Asynchronous Receiver-Transmitter.
- GPS: Global Positioning System.

### 1.5 ESTRUCTURA DEL DOCUMENTO

El documento se estructura de la siguiente manera:

/1 | La Sección 1 es la introducción e incluye una descripción detallada del proyecto y los documentos referenciados.
/2 | La Sección 2 proporciona una visión general del sistema.
/3 | La Sección 3 incluye el mapa de la red de nodos especificando las diferentes capas
/4 | La Sección 4 presenta las conclusiones del trabajo desarrollado y las posibles líneas de mejora.
/5 | Por último, se presentan las referencias del documento

### 1.6 REPOSITORIO GIT Y LISTADO DOCUMENTAL

Para la base de código y documentos pertinentes a este proyecto, se ha utilizado un repositorio Git como sistema de control de versiones, alojado en la plataforma GitHub. Para acceder al repositorio, haga click sobre el hipervínculo aquí expuesto:

https://github.com/abidanBrito/murbin

### 2 SISTEMA

### 2.1 CARACTERÍSTICAS DEL SISTEMA

El sistema aquí expuesto parte del microcontrolador ESP32 V1, o un M5Stack acoplado al micro-ordenador Raspberry Pi 3. De esta manera podemos tener una red de sensores centralizada. Además, no es necesario el uso de un convertidor Analógico-Digital externo.


Ilustración 5. Esquema de pines del ESP32.

Lo primero que se debe hacer es establecer una línea de tierra. Los pines de GND han de coincidir, y se ha de tener especial precaución con el sentido en que se acoplan los pines. Si se hiciese en una orientación errónea, se podría cortocircuitar la placa.

El circuito del Transmisor-Receptor Asíncrono Universal (UART) controla los puertos y dispositivos serie. Se utilizará para interconectar el microprocesador y el microcontrolador, mediante un protocolo de comunicación en serie. De esta manera permitimos el análisis en tiempo real con el monitor en serie del Arduino IDE o el equivalente Logcat del Android Studio. La velocidad de transferencia ha de ser la misma para maestro y esclavo, para que la transmisión de datos coincida. Nótese que la placa ESP32 solo tiene un UART. Es decir, no pueden haber varios periféricos conectados al mismo tiempo por la misma UART. La transmisión/recepción de datos se lleva a cabo por los pines TXD y RXD. No obstante, al conectar la placa al PC por el puerto microUSB, se conecta directamente al UART.

Nuestro sistema realiza lecturas analógicas de los diversos sensores a través de los pines GPIO. La mayoría de estos pines se enc uentran conectados internamente a un ADC (convertidor analógico-digital).

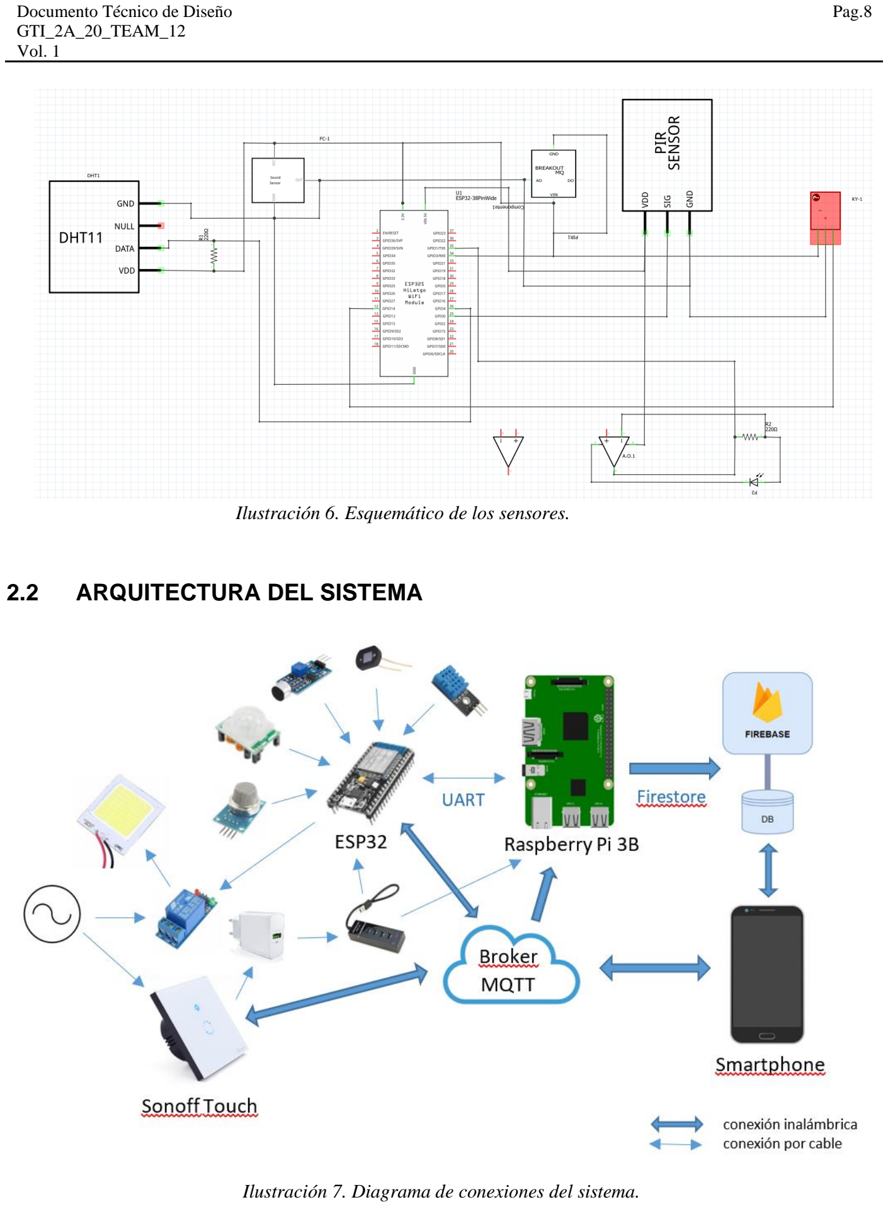
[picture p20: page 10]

Ilustración 6. Esquemático de los sensores.

### 2.2 ARQUITECTURA DEL SISTEMA

Ilustración 7. Diagrama de conexiones del sistema.

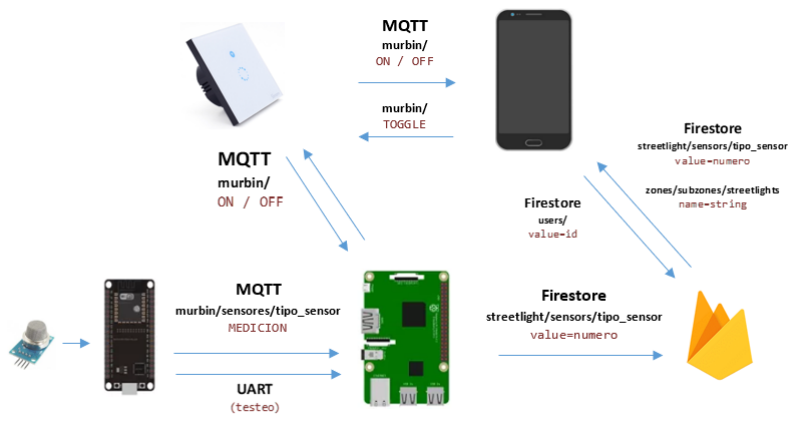
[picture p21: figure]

Ilustración 8. Diagrama de Comunicaciones del sistema.

### 3 RED DE NODOS

Se puede desglosar el camino de los datos de manera esquemática en los siguientes 5 niveles:
1. Comunicación hardware (nivel 0).
2. Acceso a la red (nivel 1).
3. Internet (nivel 2).
4. Transporte (nivel 3).
5. Aplicación (nivel 4).

En primer lugar nuestro microcontrolador realiza lecturas analógicas de los sensores a través de los pines GPIO, y con la Raspberry Pi mediante el protocolo UART (con la finalidad de enviar los datos capturados). Éstos, son enviados mediante conexión inalámbrica (Wi-Fi) a un servidor en la nube y almacenados en una base de datos NoSQL (Firebase), utilizando el protocolo IP. Ya que la conexión a Internet es la función que más consume, y no es necesario enviar datos en grandes cantidades, se podría utilizar el protocolo TCP o el UDP. Finalmente estos datos acaban en el servidor web mediante el protocolo HTTP. Nótese que, en la práctica no sería necesario tener el prototipo conectado a ningún otro dispositivo, pues es autosuficiente y los datos serían enviados directamente al servidor. A continuación, adjuntamos la siguiente ilustración a modo de ayuda visual. También se utiliza el protocolo MQTT como pasarela de comunicación entre los distintos dispositivos, para el envío y recepción de datos.


Ilustración 9. Red de nodos.

### 4 CONCLUSIONES Y LÍNEAS DE MEJORA

Tras la implementación de la segunda versión del producto (prototipo del Sprint 3) se extraen las siguientes conclusiones:
- Se ha ampliado la red de sensores interconectada de manera inalámbrica a Internet (tecnología Wi-Fi). A medida que avance el desarrollo la red de sensores seguirá creciendo en magnitud.
- Se ha terminado el wireframe (layouts) de la aplicación, teniendo en cuenta el diseño visual, el diseño de interacción y la experiencia de usuario de la aplicación móvil.
- Se ha creado terminado la base de datos NoSQL en tiempo real.
- Se ha maquetado y configurado una primera versión de la aplicación móvil (Android) con varios roles de usuario autentificados, así como el tipo de usuario invitado.
- Se han implementado nuevos actuadores y se hace uso de relés.
- Se han reemplazados los LEDs individuales por actuadores propios (anillo de LEDs y foco LED). Èsto implica concebir las funcionalidades de los distintos perfiles de usuario ya definidos.
- Se han de realizar el calibrado de los sensores para el siguiente Sprint.

### REFERENCIAS

[1] Zak Derler (2020). Smart street lighting will help future-proof our cities. (https://www.climatechangenews.com/2020/06/12/smart-street-lighting-will-help-future-proof-cities/)
[2] Esther Fuldauer (2019). Lighting the road to smart cities and sustainability. (https://www.smartcitylab.com/blog/urban-environment/lighting-the-road-to-smart-cities-and-sustainability/)
[3] Chris Teale (2020). Cities ‘finally waking up’ to the benefits of smart streetlights: survey. (https://www.smartcitiesdive.com/news/survey-smart-streetlights-LED-northeast-group/577227/) Wikipedia (2014). Intelligent street lighting. (https://en.wikipedia.org/wiki/Intelligent_street_lighting)
Wikipedia (2020). Universal asynchronous receiver-transmitter. (https://en.wikipedia.org/wiki/Universal_asynchronous_receiver-transmitter)
Campbell, Scott (2016). Basics of UART Communication. (https://www.shorturl.at/btwBS)
Loflin, Lewis (2018). Photodiode Circuit Operation and Uses. (http://www.bristolwatch.com/ele2/pdiodeTran.htm)
Universitat Politècnica de València (2017). Master en Desarrollo de Aplicaciones Android. (http://www.androidcurso.com/) Gironés, T. (2013). El gran libro de Android. Barcelona: Marcombo.

### CONTROL DEL DOCUMENTO

Título: | Documento Técnico de Diseño
Volumen: | Vol. 2
Fecha: | 19 Noviembre 2020
Autor: | Abidán Brito Clavijo
Referencia: | GTI_20_2A_TEAM_12
Nombre de fichero: | GTI_20_2A_TEAM_12-01

### FIRMAS DEL DOCUMENTO

Naturaleza del firmante | Nombre | Firma | Fecha | Rol
Autor | Abidán Brito Clavijo. | | 30/10/2020 | Miembro y manager del equipo.

Revisor

### REGISTRO DE CAMBIOS DEL DOCUMENTO

Fecha | Versión | Autor | Detalles de los cambios
20 Ocubre 2020 | Vol 1. Borrador 1 | Abidán Brito Clavijo. | Primer borrador del sistema (Sprint 1).
19 Noviembre 2020 | Vol 2. Borrador 1. | Abidán Brito Clavijo | Segundo borrador del sistema (Sprint 2).
10 Diciembre 2020 | Vol 2. Borrador 2. | Abidán Brito Clavijo | Diagrama de conexiones, comunicaciones, corrección de los protocolos.

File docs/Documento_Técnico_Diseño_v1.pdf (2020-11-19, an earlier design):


## Proyecto GTI_2A (GTI_2A_20_TEAM_12)

## Murbin - Farolas inteligentes

## Documento Técnico de Diseño

### Volumen 2

Documento Técnico de Diseño | Pag.ii
GTI_2A_20_TEAM_12
Vol. 1

### ÍNDICE

1.3 EQUIPO DE DESARROLLO E INTERESADOS EN EL PROYECTO ........4

Documento Técnico de Diseño | Pag.1

### 1 INTRODUCCIÓN

Murbin (Mobiliario urbano inteligente) plantea un prototipo de alumbrado público inteligente. Más concretamente, en nuestro caso, ser un sistema inteligente implica varias cosas: la conexión a Internet, la capacidad de realizar lecturas de diversas magnitudes físicas, así como la transmisión de éstas a posteriori y la activación automática de comportamientos preestablecidos (actuadores) en función del valor de medidas nominales. Por tanto, se trata de un proyecto que recae sobre el marco del Internet de las cosas (IoT) y requiere de numerosas tecnologías y disciplinas de la ingeniería.

Se recopila información sensible de campo, a fin de monitorizar y optimizar la actividad ambiental (intensidad de la luz, contaminación, nivel de ruido, presencia humana, geolocalización del dispositivo, etc.). Se propone implementar también un mecanismo de autoabastecimiento (célula fotovoltaica, batería y convertidor buck-boost). Para minimizar el consumo energético, se prevee la realización de las mediciones cada cierto tiempo. Ésto es configurable. Inmediatamente entraría en modo de hibernación o stand-by, hasta la siguiente captura de datos o el acaecimiento de una interrupción producida por alguna subrutina.

Para implementar las susodichas funcionalidades, se ha optado por utilizar el microcontrolador ESP32 (como esclavo), y el micro-ordenador Raspberry Pi 3 (como maestro). También son necesarios múltiples dispositivos y componentes electrónicos (resistencias, amplificadores operacionales, diodos, termistores, sensores específicos, …). El ESP32 puede ser programado utilizando la plataforma de desarrollo Arduino.

### 1.1 PROPÓSITO

En este documento se especifica el planteamiento inicial de las características técnicas del producto, así como su funcionamiento. Además, proporciona información sobre los dispositivos y tecnologías utilizados. Éste es un documento técnico dirigido a un público con conocimiento tecnológico mínimo, relativo al campo de la electrónica y la programación. Su redacción pretende exponer de manera rigurosa y objetiva las capacidades, propiedades y limitaciones del sistema. Con ello, se espera concretar las amplias posibilidades del producto.

### 1.2 ALCANCE

El término de alumbrado público inteligente hace referencia a alumbrado capaz de detectar diferentes niveles de magnitud y adaptar la intensidad de la luz de manera proporcional. Es decir, para diferentes condiciones la actuación de la farola será diferente. La intensidad baja cuando no se detecta movimiento y, por el contrario, sube cuando se detecta. Esto supone un cambio drástico de paradigma; contrasta con el tradicional alumbrado estático de intensidad variable por tiempos fijos (programado con reloj). Las posibilidades se extienden más allá de la luminosidad, permitiéndonos interactuar con los usuarios del medio público de manera acorde a la situación. Otro ejemplo sería el de cambiar la temperatura de los haces de luz en función del nivel de ruido del entorno. Así pues, es un sistema directamente ligado al desarrollo y la evolución de las Smart Cities [1] [2] [3].

Aclarado esto, los objetivos del producto son la optimización y reducción del consumo energético, el control de la contaminación en sus múltiples expresiones (sonora, lumínica y CO2), mejorar la experiencia de usuario del viandante y la creación de una interfaz homogénea y céntrica (aplicación Android) para consultas varias: búsqueda de parking, trazado de caminos, alertas personalizadas en función del nivel de ruido u otras magnitudes de interés, mapas de calor y un largo etcétera.

También estará equipado con un sistema de posicionamiento global, bien sea un recibidor GPS físico (hardware) o un par de coordenadas geográficas fijadas durante la instalación (software). Además el dispositivo ha de ser hermético; se puede estropear si alguno de sus componentes internos entra en contacto con el agua, provocando un cortocircuito.

Cabe recalcar que solo se han mencionado algunas de las funcionalidades pensadas desde un punto de vista empático con el perfil de usuario del viandante. No obstante, se han definido otros perfiles como el del técnico, el administrador y (opcionalmente) el investigador o científico. Las funcionalidades a implementar deberán ser específicas (por lo general) al tipo de usuario en cuestión. Véanse debajo los perfiles de usuario estudiados y los porcentajes aproximados que se sopesan.


Ilustración 1. Perfil de usuario (usuario).


Ilustración 2. Perfil de usuario (técnico).

Ilustración 3. Perfil de usuario (administrador).


Ilustración 4. Perfil de usuario (científico).

### 1.3 EQUIPO DE DESARROLLO E INTERESADOS EN EL PROYECTO

A continuación se listan todos los integrantes del equipo de desarrollo del proyecto, así como algunas personalidades de interés por su carácter asesorativo y/o de formación.

Miembros del equipo

Abidán Brito Clavijo

- Estudiante de 2º del grado en Tecnologías Interactivas.
- Manager del equipo.
- Desarrollo electrónico.
- Desarrollo software embebido.

Alejandro Losa García

- Estudiante de 2º del grado en Tecnologías Interactivas.
- Diseño visual y de interacción.
- Maquetación interfaz gráfica.

Francisco Javier Paños Madrona

- Estudiante de 2º del grado en Tecnologías Interactivas.
- Desarrollo de aplicación Android.

Yeray Candel Sampedro

- Estudiante de 2º del grado en Tecnologías Interactivas.
- Desarrollo electrónico.
- Desarrollo software embebido.

Raúl De La Fe Robles

- Estudiante de 2º del grado en Tecnologías Interactivas.
- Generalista.

Otros interesados en el proyecto

José Marín-Roig Ramón

- Profesor Titular en Universitat Politècnica de València.
- Product Owner.
- Asesor.

Jesús Tomás Gironés

- Profesor Titular en Universitat Politècnica de València.
- Formación teórica Android.
- Asesor.

Stella María Heras Barberá

- Profesora Asociada en Universitat Politècnica de València.
- Formación práctica Android.
- Asesora.

Enrique Colomar Pous

- Profesor Titular en Universitat Politècnica de València.
- Formación práctica de laboratorio (desarrollo electrónico).

Tomás Carlos Sogorb Devesa

- Profesor Titular en Universitat Politècnica de València.
- Formación teórica microprocesadores y acondicionadores de señal.

### 1.4 DEFINICIONES, ACRÓNIMOS Y ABREVIATURAS

- IDE: entorno de desarrollo integrado (Integrated Development Environment).
- TCP: Transmission Control Protocol.
- IP: Internet Protocol address.
- UDP: User Datagram Protocol.
- HTTP: Hypertext Transfer Protocol.
- UART: Universal Asynchronous Receiver-Transmitter.
- UART: Universal Asynchronous Receiver-Transmitter.
- I2C: Inter-Integrated Circuit.
- SPI: Serial Peripheral Interface.
- GPS: Global Positioning System.

### 1.5 ESTRUCTURA DEL DOCUMENTO

El documento se estructura de la siguiente manera:

/1 | La Sección 1 es la introducción e incluye una descripción detallada del proyecto y los documentos referenciados.
/2 | La Sección 2 proporciona una visión general del sistema.
/3 | La Sección 3 incluye el mapa de la red de nodos especificando las diferentes capas
/4 | La Sección 4 presenta las conclusiones del trabajo desarrollado y las posibles líneas de mejora.
/5 | Por último se presentan las referencias del documento

### 1.6 REPOSITORIO GIT Y LISTADO DOCUMENTAL

Para la base de código y documentos pertinentes a este proyecto, se ha utilizado un repositorio Git como sistema de control de versiones, alojado en la plataforma GitHub. Para acceder al repositorio, haga click sobre el hipervínculo aquí expuesto:

https://github.com/abidanBrito/murbin

### 2 SISTEMA

### 2.1 CARACTERÍSTICAS DEL SISTEMA

El sistema aquí expuesto parte del microcontrolador ESP32 V1, o un M5Stack acoplado al micro-ordenador Raspberry Pi 3. De esta manera podemos tener una red de sensores centralizada. Además, no es necesario el uso de un convertidor Analógico-Digital externo.


Ilustración 5. Esquema de pines del ESP32.

Lo primero que se debe hacer es establecer una línea de tierra. Los pines de GND han de coincidir, y se ha de tener especial precaución con el sentido en que se acoplan los pines. Si se hiciese en una orientación errónea, se podría cortocircuitar la placa.

El circuito del Transmisor-Receptor Asíncrono Universal (UART) controla los puertos y dispositivos serie. Se utilizará para interconectar el microprocesador y el microcontrolador, mediante un protocolo de comunicación en serie. De esta manera permitimos el análisis en tiempo real con el monitor en serie del Arduino IDE o el equivalente Logcat del Android Studio. La velocidad de transferencia ha de ser la misma para maestro y esclavo, para que la transmisión de datos coincida. Nótese que la placa ESP32 solo tiene un UART. Es decir, no pueden haber varios periféricos conectados al mismo tiempo por la misma UART. La transmisión/recepción de datos se lleva a cabo por los pines TXD y RXD. No obstante, al conectar la placa al PC por el puerto microUSB, se conecta directamente al UART.

Nuestro sistema utiliza el protocolo I2C. Se trata de un protocolo de comunicación en serie, bidireccional (half-duplex) y síncrono. El bus I2C se conecta a todos los sensores. Es el mismo para todos. La conexión al microcontrolador se lleva a cabo a través de dos líneas o buses:
- SDA ( data): primero se manda el bit de inicio (start) y luego la secuencia; el tren de datos en sí. Finalmente, un bit de acuerdo y otro de parada.
- SCL / CLK (clock): bus para el reloj. Marca el ritmo o compás, por así decirlo.

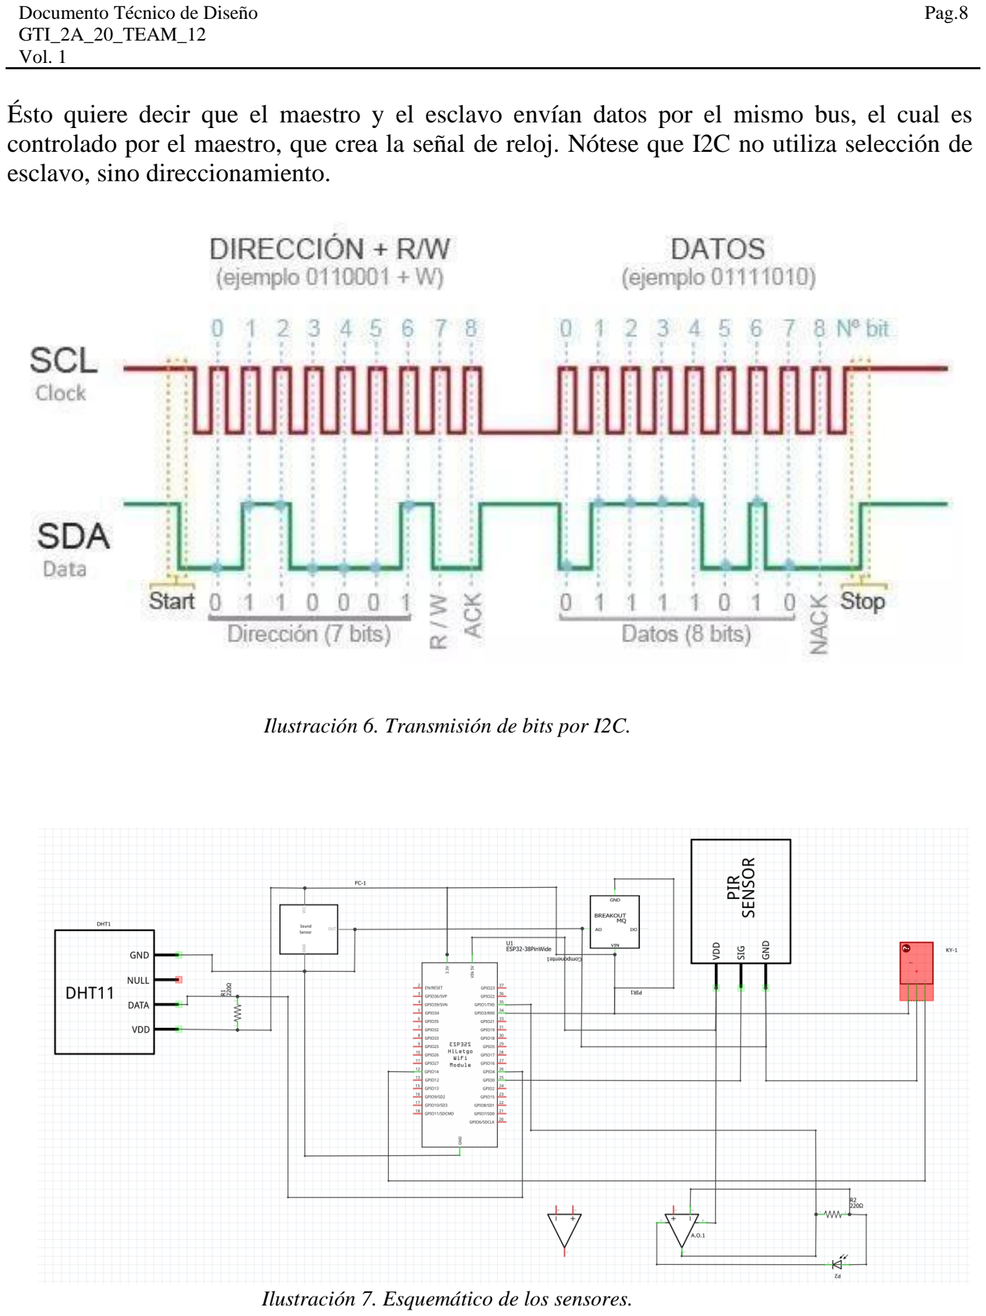
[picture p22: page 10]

Ésto quiere decir que el maestro y el esclavo envían datos por el mismo bus, el cual es controlado por el maestro, que crea la señal de reloj. Nótese que I2C no utiliza selección de esclavo, sino direccionamiento.

Ilustración 6. Transmisión de bits por I2C.

Ilustración 7. Esquemático de los sensores.

### 2.2 ARQUITECTURA DEL SISTEMA

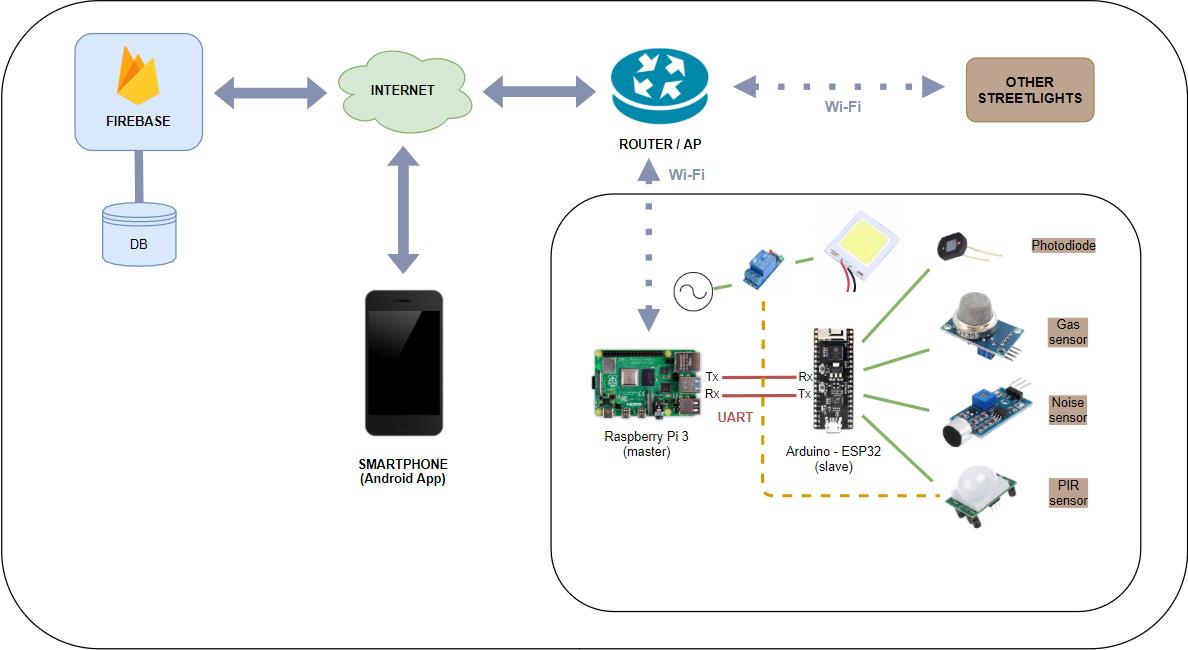
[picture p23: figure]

Ilustración 8. Diagrama del sistema.

### 3 RED DE NODOS

Se puede desglosar el camino de los datos de manera esquemática en los siguientes 5 niveles:
1. Comunicación hardware (nivel 0).
2. Acceso a la red (nivel 1).
3. Internet (nivel 2).
4. Transporte (nivel 3).
5. Aplicación (nivel 4).

En primer lugar nuestro microcontrolador se comunica con los sensores mediante el protocolo I2C o SPI, y con la Raspberry Pi mediante el protocolo UART (con la finalidad de enviar los datos capturados). Éstos, son enviados mediante conexión inalámbrica (Wi-Fi) a un servidor en la nube y almacenados en una base de datos NoSQL (Firebase), utilizando el protocolo IP. Ya que la conexión a Internet es la función que más consume, y no es necesario enviar datos en grandes cantidades, se podría utilizar el protocolo TCP o el UDP. Finalmente estos datos acaban en el servidor web mediante el protocolo HTTP. Nótese que, en la práctica no sería necesario tener el prototipo conectado a ningún otro dispositivo, pues es autosuficiente y los datos serían enviados directamente al servidor. A continuación, adjuntamos la siguiente ilustración a modo de ayuda visual. No obstante, en el nivel 0 deberían estar representados los ya mencionados protocolos I2C y SPI.


Ilustración 9. Red de nodos.

### 4 CONCLUSIONES Y LÍNEAS DE MEJORA

Tras la implementación de la segunda versión del producto (prototipo del Sprint 2) se extraen las siguientes conclusiones:
- Se ha ampliado la red de sensores interconectada de manera inalámbrica a Internet (tecnología Wi-Fi). A medida que avance el desarrollo la red de sensores seguirá creciendo en magnitud.
- Se ha desarrollado el wireframe de la apliación, teniendo en cuenta el diseño visual, el diseño de interacción y la experiencia de usuario de la aplicación móvil.
- Se ha creado una base de datos NoSQL en tiempo real.
- Se ha maquetado y configurado una primera versión de la aplicación móvil (Android) con varios roles de usuario autentificados, así como el tipo de usuario invitado.
- Se han implementado nuevos actuadores y se hace uso de relés.
- Se deben reemplazar los actuadores simulados con diodos LED por dispositivos o sistemas propios del contexto y funcionalidad en cuestión. Èsto implica concebir las funcionalidades de los distintos perfiles de usuario ya definidos.
- Se deben calibrar y testear los diferentes sensores para el siguiente Sprint.
- Se puede optimizar la fase de desarrollo electrónico adquiriendo el material necesario con la suficiente antelación, así como una mejor gestión de éste entre los miembros involucrados.
- No se ha tenido en cuenta el consumo energético, por ser la primera iteración. No obstante, es algo a tener presente para iteraciones futuras.

### 5 REFERENCIAS

[1] Zak Derler (2020). Smart street lighting will help future-proof our cities. (https://www.climatechangenews.com/2020/06/12/smart-street-lighting-will-help-future-proof-cities/)
[2] Esther Fuldauer (2019). Lighting the road to smart cities and sustainability. (https://www.smartcitylab.com/blog/urban-environment/lighting-the-road-to-smart-cities-and-sustainability/)
[3] Chris Teale (2020). Cities ‘finally waking up’ to the benefits of smart streetlights: survey. (https://www.smartcitiesdive.com/news/survey-smart-streetlights-LED-northeast-group/577227/) Wikipedia (2014). Intelligent street lighting. (https://en.wikipedia.org/wiki/Intelligent_street_lighting)
Wikipedia (2020). Universal asynchronous receiver-transmitter. (https://en.wikipedia.org/wiki/Universal_asynchronous_receiver-transmitter)
Campbell, Scott (2016). Basics of UART Communication. (https://www.shorturl.at/btwBS)
Loflin, Lewis (2018). Photodiode Circuit Operation and Uses. (http://www.bristolwatch.com/ele2/pdiodeTran.htm)
Universitat Politècnica de València (2017). Master en Desarrollo de Aplicaciones Android. (http://www.androidcurso.com/) Gironés, T. (2013). El gran libro de Android. Barcelona: Marcombo.

### CONTROL DEL DOCUMENTO

Título: | Documento Técnico de Diseño
Volumen: | Vol. 2
Fecha: | 19 Noviembre 2020
Autor: | Abidán Brito Clavijo
Referencia: | GTI_20_2A_TEAM_12
Nombre de fichero: | GTI_20_2A_TEAM_12-01

### FIRMAS DEL DOCUMENTO

Naturaleza del firmante | Nombre | Firma | Fecha | Rol
Autor | Abidán Brito Clavijo. | | 30/10/2020 | Miembro y manager del equipo.

Revisor

### REGISTRO DE CAMBIOS DEL DOCUMENTO

Fecha | Versión | Autor | Detalles de los cambios
20 Ocubre 2020 | Vol 1. Borrador 1 | Abidán Brito Clavijo. | Primer borrador del sistema (Sprint 1).
19 Noviembre 2020 | Vol 2. Borrador 1. | Abidán Brito Clavijo | Segundo borrador del sistema (Sprint 2).

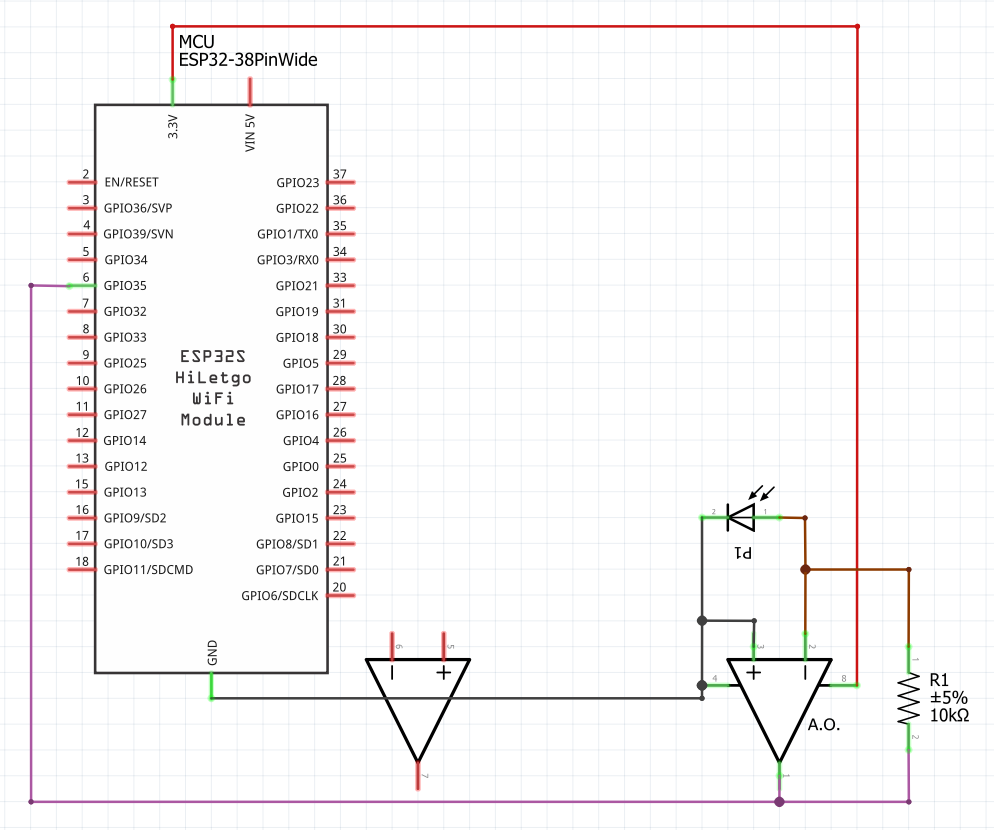
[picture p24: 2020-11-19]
schematics/light_intensity/light_intensity_schematic01.png

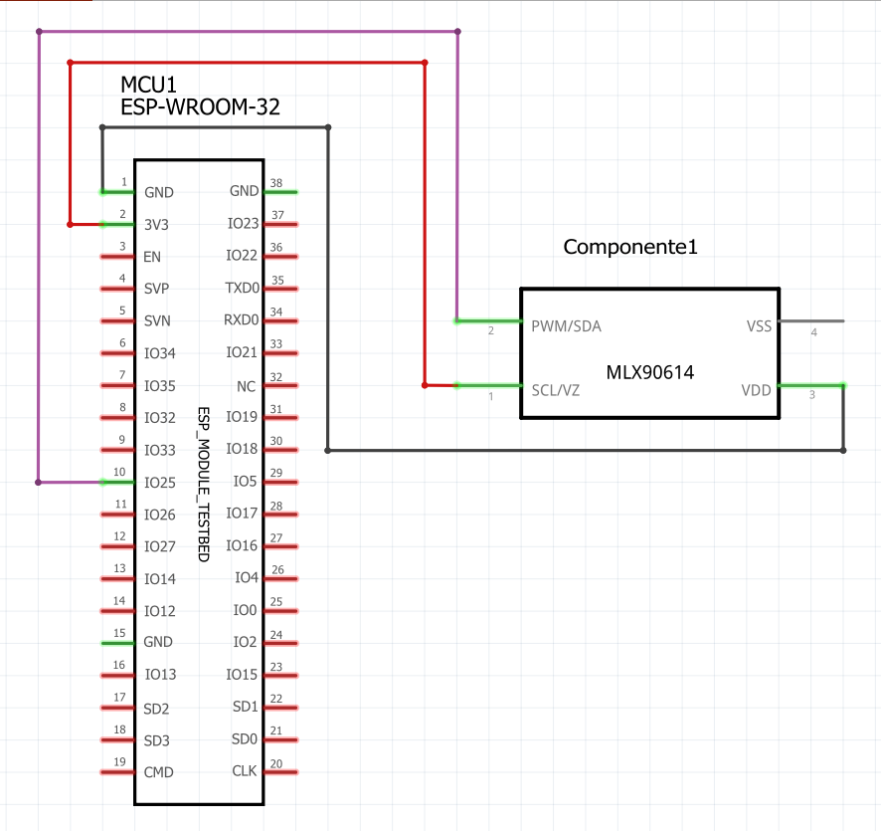
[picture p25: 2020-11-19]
schematics/pir/pir_schematic01.png

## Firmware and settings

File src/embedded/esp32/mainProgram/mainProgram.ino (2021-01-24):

#include <M5Stack.h>
#include "Sensores.h"
#include "DHT.h" //para sensor DHT
#include "esp_freertos_hooks.h"
#define configUSE_IDLE_HOOK 1

/*********************************/
/*        Definiendo MQTT        */
/*********************************/
#include <ArduinoMqttClient.h>
#include <WiFiClient.h>
#include <WiFiGeneric.h>
#include <WiFiMulti.h>
#include <WiFiScan.h>

//includes udp
#include "AsyncUDP.h"
#include <TimeLib.h>

AsyncUDP udp;

#ifdef __AVR__
  #include <avr/power.h>
#endif

#if defined(ARDUINO_SAMD_MKRWIFI1010) || defined(ARDUINO_SAMD_NANO_33_IOT) || defined(ARDUINO_AVR_UNO_WIFI_REV2)
  #include <WiFiNINA.h>
#elif defined(ARDUINO_SAMD_MKR1000)
  #include <WiFi101.h>
#elif defined(ARDUINO_ESP8266_ESP12)
  #include <ESP8266WiFi.h>
#endif

char ssid[] = "Yeraysa-WLAN";        // Network SSID (name)
char pass[] = "12345678";            // Network password (use for WPA, or use as key for WEP)

WiFiClient wifiClient;
MqttClient mqttClient(wifiClient);

const char broker[] = "broker.hivemq.com";
int        port     = 1883;
const char topic[]  = "ycansam/practica/POWER";

const long interval = 1000;
unsigned long previousMillis = 0;

/*********************************/
/*   Definiendo Pines sensores   */
/*********************************/
const int sensorCO2 = 34;    
const int sensorLUM = 35;
const int sensorRetro = 27; 
const int sensorRUIDO = 33;
Adafruit_NeoPixel pixels = Adafruit_NeoPixel(NUMPIXELS, sensorRetro, NEO_GRB + NEO_KHZ800);

/***********************************************/
/*   Definiendo Valores Iddle Hook sensores    */
/***********************************************/
int contador_sensores = 0;

int lastVal_CO2 = 4095;
int lastVal_Noise = 4095;
int lastVal_Humidity = 100;
int lastVal_Temp = 50;


//Para sensor temperatura
#define DHTTYPE DHT11   // DHT 11
const int DHTPin = 26;
DHT dht(DHTPin, DHTTYPE);

/*********************************/
/* Definiendo semaforos sensores */
/*********************************/

//Declaracion manejadores de los semaforos binarios
SemaphoreHandle_t SCO2 = NULL;
SemaphoreHandle_t SLIGHT = NULL;
SemaphoreHandle_t SNOISE = NULL;
SemaphoreHandle_t SHUM = NULL;

SemaphoreHandle_t SMQTT = NULL; //declaracion semaforo que inicia el envio de mqtt

//declaracion semaforo interrupcion
SemaphoreHandle_t xSemaphore_Noise = NULL;
SemaphoreHandle_t xSemaphore_PaintLeds = NULL;
//flag para llegada mensaje mqtt TOGGLE
int ISR_MQTT = 0;


// Declaracion objetos de estructura hw_timer_t
hw_timer_t * timer0 = NULL; //timer para RetroLed
hw_timer_t * timer1 = NULL; //timer para mqtt
hw_timer_t * timer2 = NULL; //timer para sensor PIR

volatile int Flag_ISR_Timer0= 0;
volatile int Flag_ISR_Timer1 = 0;

void IRAM_ATTR ISR_Timer0(){
  Flag_ISR_Timer0 = 1;
}

void IRAM_ATTR ISR_Timer1(){
  Flag_ISR_Timer1 = 1;
}



void interr_task_noise(void *pvParameter)
{
  int value;
  int limit;
  while(1) {
    if(xSemaphoreTake(xSemaphore_Noise,portMAX_DELAY)){
      if (xSemaphoreTake(xSemaphore_PaintLeds, portMAX_DELAY)){
       while(analogRead(sensorRUIDO) > 400){
        Serial.println("INTR NOISE: ");
        pixels.clear();
        value = analogRead(sensorRUIDO);
        Serial.print(analogRead(sensorRUIDO));
        limit = 4095;
        int bright_value = (value * 255) / limit;
        int pin_value = round((value * 24) / limit);
        
        for(int i = 0; i < pin_value; i++)
        {
          if(bright_value >= 125) pixels.setPixelColor(i, pixels.Color(255, 0, 0));
          else pixels.setPixelColor(i, pixels.Color(0, 255, 0));
        }
        pixels.setBrightness(bright_value);
        pixels.show(); 
        vTaskDelay(250 / portTICK_PERIOD_MS);
        pixels.clear();
        pixels.setPixelColor(24, pixels.Color(0, 0, 0));
        pixels.show(); 
        vTaskDelay(250 / portTICK_PERIOD_MS);
      }
      pintarUltimoValor();
      xSemaphoreGive(xSemaphore_PaintLeds);
     }
    }
  }
}

/*********************************/
/*  Definiendo tareas sensores   */
/*********************************/
void taskCo2(void *pvParameter)
{
  String sensor = "co2";
  while(1) {
    if(xSemaphoreTake(SMQTT,portMAX_DELAY)){
    Serial.println("Ejecutando tarea Co2");
    lastVal_CO2 = analogRead(sensorCO2);

    int percent = (analogRead(sensorCO2) * 100) / 4095;
    sendMqtt(sensor,(int) percent);
    vTaskDelay(1000 / portTICK_PERIOD_MS);
    xSemaphoreGive(SCO2);
    }
  }
}

void taskLight(void *pvParameter)
{
  String sensor = "brightness";
    while(1) {
      if(xSemaphoreTake(SCO2,portMAX_DELAY)){
        Serial.println("Ejecutando tarea LUM");
 
        // Calibrated upon saturation voltage
        int percent = (analogRead(sensorLUM) * 100) / 3072;
        if (percent > 100) {
          percent = 100;
        }
        
        sendMqtt(sensor,(int) percent);
        vTaskDelay(1000 / portTICK_PERIOD_MS);
        xSemaphoreGive(SLIGHT);
      }
   }
}

void taskNoise(void *pvParameter)
{
  String sensor = "noise";
  while(1) {
    if(xSemaphoreTake(SLIGHT,portMAX_DELAY)){
      Serial.println("Ejecutando tarea Noise");
      lastVal_Noise = analogRead(sensorRUIDO);
      sendMqtt(sensor, lastVal_Noise);
      vTaskDelay(1000 / portTICK_PERIOD_MS);
      xSemaphoreGive(SNOISE);
    }
  }
}

void taskHumidity(void *pvParameter)
{
  String sensor = "humidity";
  while(1) {
    if(xSemaphoreTake(SNOISE,portMAX_DELAY)){
      Serial.println("Ejecutando tarea Humedad");
      int humValue = dht.readHumidity();
      if (humValue <= 100) {
        lastVal_Humidity = humValue;
      }
      
      sendMqtt(sensor, lastVal_Humidity);
      vTaskDelay(1000 / portTICK_PERIOD_MS);
      xSemaphoreGive(SHUM);
    }
  }
}
int counterSleep = 0;
void taskTemp(void *pvParameter)
{
  String sensor = "temperature";
  while(1) {
    if(xSemaphoreTake(SHUM,portMAX_DELAY)){
      Serial.println("Ejecutando tarea Temperatura");
      int tempValue = dht.readTemperature();
      if (tempValue <= 50) {
        lastVal_Temp = tempValue;
      }
      
      sendMqtt(sensor, lastVal_Temp);
      vTaskDelay(1000 / portTICK_PERIOD_MS);

      counterSleep++;

     if(counterSleep == 4){
    //  Serial.println("light_sleep_enter");
     // esp_sleep_enable_timer_wakeup(10000000); // 10 seconds
    //  int ret = esp_light_sleep_start();
   //   Serial.printf("light_sleep: %d\n", ret);
   //counterSleep=0;
     }
    }
  }
}

void setup() 
{
  M5.begin();
  Serial.begin(115200);
  //pixels.begin(); 
  
  // Procesos MQTT
  while (!Serial) {
    ; //Espera al Serial port para conectarse
  }

  // Conexion a wifi
  Serial.print("Attempting to connect to WPA SSID: ");
  Serial.println(ssid);
  WiFi.mode(WIFI_STA);
  while (WiFi.begin(ssid, pass) != WL_CONNECTED) {
    // Si falla se retira
    Serial.println("Trying to connect..");
    delay(5000);
  }

  Serial.println("You're connected to the network");
  Serial.println();

  // mqttClient.setId("ArduinoClient1");

  Serial.print("Attempting to connect to the MQTT broker: ");
  Serial.println(broker);
  while(1){
    if (mqttClient.connect(broker, port)){
      break;
    }
  }
  if (!mqttClient.connect(broker, port)) {
    Serial.print("MQTT connection failed! Error code = ");
    Serial.println(mqttClient.connectError());

    while (1);
  }

  Serial.println("You're connected to the MQTT broker!");
  Serial.println();

  mqttClient.onMessage(onMqttMessage);

  Serial.print("Subscribing to topic: ");
  Serial.println(topic);
  Serial.println();

  // Suscripcion a un 'topic'
  mqttClient.subscribe(topic);

  Serial.print("Waiting for messages on topic: ");
  Serial.println(topic);
  Serial.println();

if(udp.listen(1234)) {
    Serial.print("UDP Listening on IP: ");
    Serial.println(WiFi.localIP());
    udp.onPacket([](AsyncUDPPacket packet) {
    Serial.write(packet.data(), packet.length());
    Serial.println();
    });
  }
  // Fin procesos mqtt
 
  // Inicializa el sensor de temperatura y humedad
  dht.begin();
   
  // Configurando los pines de entrada y salida
  pinMode(sensorCO2, INPUT);       // Sensor CO2
  pinMode(sensorLUM, INPUT);       // Sensor LUZ
  pinMode(sensorRUIDO, INPUT);       // Sensor LUZ
  detectar_movimiento();           // Llama a la funcion para programar la interrupcion del sensor de movimiento.

  // Configurando Leds
  pinMode(LED_PIR, OUTPUT);

  // Timer 0: alarma 4s RetroLed
  timer0 = timerBegin(0, 80, true);  // Timer 0 (TIMG0_T0),Periodo TB_clk = 12.5 ns * TIMGn_Tx_CLK_PRESCALE = 12.5 ns * 80 -> 1000 ns = 1 us, countUp
  timerAttachInterrupt(timer0, &ISR_Timer0, true); // edge (not level) triggered 
  timerAlarmWrite(timer0, 3000000, true); // Alarma con autorecarga, Periodo alarma = 3000000 * 1 us = 6 s 

  // Timer 1: alarma 20s Enviar Valores Mqtt
  timer1 = timerBegin(1, 80, true);  // Timer 1 (TIMG0_T1),Periodo TB_clk = 12.5 ns * TIMGn_Tx_CLK_PRESCALE = 12.5 ns * 80 -> 1000 ns = 1 us, countUp
  timerAttachInterrupt(timer1, &ISR_Timer1, true); // edge (not level) triggered 
  timerAlarmWrite(timer1, 6500000, true); // Alarma con autorecarga, Periodo alarma = 20000000 * 1 us = 20 s 



  timerAlarmEnable(timer0); // Habilitar alarma
  timerAlarmEnable(timer1); // Habilitar alarma

  // Creacion semaforos binarios
   SCO2 = xSemaphoreCreateBinary();
   SLIGHT = xSemaphoreCreateBinary();
   SNOISE = xSemaphoreCreateBinary();
   SHUM = xSemaphoreCreateBinary();
   SMQTT = xSemaphoreCreateBinary();
    
  // Creacion de tareas
   xTaskCreate(&taskCo2, "tarea1 CO2", 10000, NULL, 3, NULL);
   xTaskCreate(&taskLight, "tarea2 LIGHT", 10000, NULL,3, NULL);
   xTaskCreate(&taskNoise, "tarea3 NOISE", 10000, NULL, 3, NULL);
   xTaskCreate(&taskHumidity, "tarea4 HUMIDITY", 10000, NULL,3, NULL);
   xTaskCreate(&taskTemp, "tarea5 TEMPERATURE", 10000, NULL, 3, NULL);


// se crea el semáforo binario
   xSemaphore_Noise = xSemaphoreCreateBinary();
   xSemaphore_PaintLeds = xSemaphoreCreateMutex();

// Creacion Tareas de interrupciones
   xTaskCreate(&interr_task_noise, "Interrupcion Ruido", 2048, NULL, 1, NULL);
// Idle task hook
    esp_register_freertos_idle_hook(IddleHook);

//  esp_sleep_enable_ext0_wakeup(GPIO_NUM_12,1); //despierta mediante sensor PIR
  //esp_sleep_enable_ext1_wakeup(GPIO_NUM_4,1); //despierta mediante sensor ruido
}

/* Funcion IdleHook */
bool IddleHook(void){
     
  if(analogRead(sensorRUIDO) > 400){
    xSemaphoreGive(xSemaphore_Noise);
  }
  return true;
}

void pintarUltimoValor(){
  int limit;
  int value;
  
  if(contador_sensores == 0){
    Serial.println("****CO2****");
   limit = 4095;
   value = lastVal_CO2;
  }
  if(contador_sensores== 1){
    Serial.println("****NOISE****");
     limit = 4095;
   value = lastVal_Noise;
  }
  if(contador_sensores== 2){
    Serial.println("****HUMIDITY****");
     limit = 100;
   value = lastVal_Humidity;
  }
  if(contador_sensores== 3){
    Serial.println("****TEMP****");
     limit = 50;
   value = lastVal_Temp;
  }
   pixels.clear();
      
      int bright_value = (value * 255) / limit;
      int pin_value = round((value * 24) / limit);
      
      for(int i=0;i<pin_value;i++)
      {
                 if(bright_value >= 125) pixels.setPixelColor(i, pixels.Color(255, 0, 0));
          else pixels.setPixelColor(i, pixels.Color(0, 255, 0));
      }

      pixels.setBrightness(bright_value);
      pixels.show();   
}

void printRetroLedSensors(){
  int limit;
  int value;
  char sensor[16];
  int valueLCD = 0;
  
  if(contador_sensores == 0){
   Serial.println("****CO2****");
   limit = 4095;
   value = lastVal_CO2;
   valueLCD = (value * 100) / 4095;
   strcpy(sensor, "CO2: percent = ");
  }
  
  if(contador_sensores== 1){
    Serial.println("****NOISE****");
     limit = 4095;
   value = lastVal_Noise;
   valueLCD = (value*100)/4095;
   strcpy(sensor, "Noise: Db =");
  }
  
  if(contador_sensores== 2){
   Serial.println("****HUMIDITY****");
   limit = 100;
    value =lastVal_Humidity;
    Serial.print(value);
    if (xSemaphoreTake( xSemaphore_PaintLeds, portMAX_DELAY )){
   pixels.clear();
      int bright_value = (lastVal_Humidity * 255) / limit;
      int pin_value = round((lastVal_Humidity * 24) / limit);
      
      for(int i=0;i<pin_value;i++)
      {
                 if(bright_value >= 125) pixels.setPixelColor(i, pixels.Color(255, 0, 0));
          else pixels.setPixelColor(i, pixels.Color(0, 255, 0));
      }

      pixels.setBrightness(bright_value);
      pixels.show(); 

      xSemaphoreGive(xSemaphore_PaintLeds);  
  }
   
   strcpy(sensor, "Humidity: Percent = ");
  }
   
  if(contador_sensores == 3){
    Serial.println("****TEMP****");
    limit = 50;
    value = dht.readTemperature();
    strcpy(sensor, "Temp: C· = ");
  }

  //mensaje envio pantalla lcd udp
      char texto[100];
      if(value != lastVal_Temp && value != lastVal_Humidity){
        sprintf (texto, "%s : %d " ,sensor,valueLCD);
      }else{
        sprintf (texto, "%s : %d " ,sensor,value);
      }
      
      
      //Send broadcast on port 1234
      udp.broadcastTo(texto,1234);
  if (xSemaphoreTake( xSemaphore_PaintLeds, portMAX_DELAY )){
   pixels.clear();
      int bright_value = (value * 255) / limit;
      int pin_value = round((value * 24) / limit);
      
      for(int i=0;i<pin_value;i++)
      {
                 if(bright_value >= 125) pixels.setPixelColor(i, pixels.Color(255, 0, 0));
          else pixels.setPixelColor(i, pixels.Color(0, 255, 0));
      }

      pixels.setBrightness(bright_value);
      pixels.show(); 

      xSemaphoreGive(xSemaphore_PaintLeds);  
  }
  contador_sensores++;
  if(contador_sensores > 3){
    contador_sensores = 0;
  }


 
  Flag_ISR_Timer0 = 0;
 
}
unsigned long delayStart = 0; // the time the delay started
bool delayRunning = false; // true if still waiting for delay to finish

void loop() 
{
  mqttClient.poll();

  unsigned long currentMillis = millis();
  
   // Variable que detecta si la interrupcion ha sido producida
   if (movimiento){  
       digitalWrite(LED_PIR,HIGH);
       delay(3000);
      movimiento= 0;
   }
   else if(movimiento == 0){
    if(ISR_MQTT == 0){
       digitalWrite(LED_PIR,LOW);
    }
   }
   if(ISR_MQTT == 1){
    digitalWrite(LED_PIR,HIGH);
   }
   if(ISR_MQTT == 0){
    digitalWrite(LED_PIR,LOW);
   }

//timer cada 6 segundos en el retroled
   if (Flag_ISR_Timer0) {
    printRetroLedSensors();
    
  }
//timer cada 20 segundos en el mqtt
  if (Flag_ISR_Timer1) {
    xSemaphoreGive(SMQTT);
    Flag_ISR_Timer1 = 0;
  }

    
}

void sendMqtt(String sensor, int v)
{
  String topicSend  = String("equipo1-2/murbin/sensors/") + String(sensor);

  mqttClient.poll();
  
  // avoid having delays in loop, we'll use the strategy from BlinkWithoutDelay
  // see: File -> Examples -> 02.Digital -> BlinkWithoutDelay for more info
  unsigned long currentMillis = millis();
  if (currentMillis - previousMillis >= interval) {
    // save the last time a message was sent
    previousMillis = currentMillis;

    Serial.println("Sending message to topic: ");
    Serial.println(topicSend);
    Serial.print("value: ");
    Serial.print(v);

    // send message, the Print interface can be used to set the message contents
    mqttClient.beginMessage(topicSend);
    mqttClient.println(v);
    mqttClient.endMessage();

    Serial.println(" ");
    Serial.println(" ");
  }
}

//recieving mqtt message
void onMqttMessage(int messageSize) {
 // we received a message, print out the topic and contents
  String topic = mqttClient.messageTopic();
  String payload = mqttClient.readString();
  Serial.println("incoming: " + topic + ", length: " + messageSize + " ");
  Serial.println(payload);
  if (payload == "ON") {
    Serial.println("Emcendiendo farola..");
    ISR_MQTT = 1;
    digitalWrite(LED_PIR,HIGH);
  } else if (payload == "OFF") {
    Serial.println("Apagando farola..");
    ISR_MQTT = 0;
    digitalWrite(LED_PIR,LOW);
  } else if (payload == "TOGGLE") {
    if(ISR_MQTT == 1){
      Serial.println("Apagando farola..");
      ISR_MQTT = 0;
      digitalWrite(LED_PIR,LOW);
    }else if(ISR_MQTT == 0){
      Serial.println("Emcendiendo farola..");
      ISR_MQTT = 1;
      digitalWrite(LED_PIR,HIGH);
    }
  }
  Serial.println();

  Serial.println();
}

/*********************************/
/*  Definiendo INTERRUPCION PIR  */
/*********************************/
void  IRAM_ATTR detectarMovimiento(void* arg)
{
  movimiento=1;
  delayRunning = true; // not finished yet
 
  Serial.println(" -- Movimiento detectado --"); 
}

void detectar_movimiento()
{
  // Configurar pines
  gpio_set_direction(sensorPIR, GPIO_MODE_INPUT);
  
  // Configurar interrupciones en pines
  gpio_set_intr_type(sensorPIR, GPIO_INTR_POSEDGE);
  
  // Setting pull down mode.
  gpio_set_pull_mode(sensorPIR, GPIO_PULLDOWN_ONLY);
  
  // install ISR service with default configuration
  gpio_install_isr_service(sensorPIR_FLAG_LEVEL);
  
  // attach the interrupt service routine
  gpio_isr_handler_add(sensorPIR, detectarMovimiento, NULL);
}

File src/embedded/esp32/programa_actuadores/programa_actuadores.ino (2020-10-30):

//PROGRAMA ACTUADORES //

int sensorCO2 = 34;    
int sensorLUM = 35; 
const int PIRPin = 36; // pin de entrada (para el sensor PIR) 


#define LED   5 //defino el led como pin 36

#define LUM_SENSOR  'L'       // defino el primer sensor de manera escalable
#define CO2_SENSOR  'C'       // defino el segundo sensor de manera escalable
#define PIR_SENSOR  'P'       // defino el tercer sensor de manera escalable

void setup() {
  // put your setup code here, to run once:
  Serial.begin(115200);
  //Configurando los pines de entrada y salida
  pinMode(PIRPin, INPUT);   
  pinMode(sensorCO2, INPUT);       // Sensor CO2
  pinMode(sensorLUM, INPUT);       // Sensor LUZ
  pinMode(LED, OUTPUT);
}

void loop() {

  
   if (Serial.available() > 0) {
      char command = (char) Serial.read(); 
      switch (command) {
         case CO2_SENSOR:
         Serial.print("Enviando informacion.. "); 
            sensor_CO2(sensorCO2, LED);
            break;
         case LUM_SENSOR: 
         Serial.print("Enviando informacion.. "); 
          Serial.print(String(sensorLUM));
         sensor_LUM(sensorLUM, LED);
            break; 
         case PIR_SENSOR: 
         Serial.print("Enviando informacion.. "); 
         Serial.print(String(PIRPin));
            sensor_PIR(PIRPin, LED);
            break;
            
      } 
   }
}

//programa sensor Co2
void sensor_CO2(int pin_mq, int ledPIN){
  
  boolean mq_estado = digitalRead(pin_mq);//Leemos el sensor
  
  if(mq_estado) //si la salida del sensor es 1
  {
    digitalWrite(ledPIN , LOW);    // poner el Pin en LOW
    Serial.println("Sin presencia de alcohol");
    
  }
  else //si la salida del sensor es 0
  {
    digitalWrite(ledPIN , HIGH);   // poner el Pin en HIGH
    Serial.println("Alcohol detectado");
    delay(2000); 
    digitalWrite(ledPIN , LOW);
  }
}

//programa sensor luz
void sensor_LUM(int pin, int led){
  int valor = analogRead(pin_mq);
  Serial.println(valor);
  //si el valor de la luz es mayor a 1000, el led se enciende y se apagara a los 2 segundos
  if(valor > 1000){
    Serial.println("Se ha dedectado luz");
    digitalWrite(led, HIGH);
    delay(2000); // Wait for 1000 millisecond(s)
    digitalWrite(led, LOW);
  }else{
    Serial.println("No Hay luz");
    digitalWrite(led, LOW);
  }
}

//programa sensor luz
void sensor_PIR(int PIRPin, int LEDpin){
  
   val = digitalRead(PIRPin); //Lectura de datos
   if (val == HIGH) { //si está activado
     
      digitalWrite(LEDPin, HIGH);  //LED ON
      if (pirState == LOW){ //si previamente estaba apagado
      
        Serial.println("Sensor activado");
        pirState = HIGH;
      }
   } else {   //si esta desactivado
   
      digitalWrite(LEDPin, LOW); // LED OFF
      if (pirState == HIGH){  //si previamente estaba encendido
      
        Serial.println("Sensor parado");
        pirState = LOW;
      }
   }
}
/*
//PROGRAMA UTILIZADO PARA M5STACK


#include <M5Stack.h>

const int ledPIN = 5;
int pin_mq = 2;

void setup() { 
  Serial.begin(9600);
 // M5.begin();
 // M5.Lcd.setTextSize(2);
 // M5.Lcd.print("Pin GPIO value: ");
  pinMode(pin_mq, INPUT);
  pinMode(ledPIN , OUTPUT); 
}


void loop() {
  int valor = analogRead(pin_mq);
  boolean mq_estado = digitalRead(pin_mq);//Leemos el sensor
  Serial.println(valor);
  if(valor < 3000) //si la salida del sensor es 1
  {
    //M5.Lcd.println("Sin presencia de alcohol");
    digitalWrite(ledPIN , LOW);    // poner el Pin en LOW
    Serial.println("Sin presencia de alcohol");
    
  }
  else //si la salida del sensor es 0
  {
    digitalWrite(ledPIN , HIGH);   // poner el Pin en HIGH
    Serial.println("Alcohol detectado");
  }
  delay(2000); 
}
*/

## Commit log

2020-10-28 fix: Improved some layouts and button interactions
    T018
2020-10-29 feat: added rpi3 (master) uart demo program
2020-10-29 feat: added esp32 (slave) sensors controller program
2020-10-29 Programa de arduino
    Los actuadores funcionan cuando detectan algun tipo de dato
2020-10-31 feat: added light intensity sensor schematic
    [light_intensity.fzz]
2020-10-31 feat: added schematic screenshots
2020-11-11 fix: modified directory structure and filename for clarity
    [mainProgram.ino]
2020-11-11 feat: added co2 sensor and calibration thresholds
2020-11-16 feat: added co2 and luminosity sensors calibration
2020-11-16 refactor: deleted redundant switch
2020-11-17 feat: New Sensors
    Se han añadido los sensores de temperatura, pir y sonido. Con interrupciones clases y escalable
2020-11-18 fix: modified interruption
    La interrupcion que provoca el pir esta ahora en el main
    [mainProgram.ino]
2020-11-18 fix: Interruption solved
    Habia un problema con la interrupcion(no se producia)
    [mainProgram.ino]
2020-11-19 fix: inverted photodiode polarity
    [light_intensity.fzz]
2020-11-19 feat: added method to get sensor data
2020-11-19 fix: added lost switch block back
    [mainProgram.ino]
2020-11-19 feat: proper uart data sending approach
2020-11-19 feat: reading sensors readings and pushing to firestore
2020-11-19 feat: added fritzing pir schematic
    [pir.fzz]
2021-01-21 Fixed Mqtt Raspberry
2021-01-21 ESP FIXES AND FEATS
    Fix mqtt
    Feat new interruptions
    Feat 3 Timers
    [m5stack_udp_slave.ino, mainProgram.ino]
2021-01-21 Fix: 3 lines changed
    [mainProgram.ino]
2021-01-24 feat: arduino final fixes
    [m5stack_udp_slave.ino, mainProgram.ino]
2021-01-24 fix: rpi controller fixes
    [MainActivityMQTT.java]
2021-01-24 feat: added DHT sensor library
